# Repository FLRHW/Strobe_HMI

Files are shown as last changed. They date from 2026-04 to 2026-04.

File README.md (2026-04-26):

<h1 align="center">HMI board</h1>

<p align="center" width="100%">
  <a href="https://github.com/FLRHW/Strobe_HMI/actions/workflows/ci.yaml">
    
  </a>
</p>

<p align="center" width="100%">
    
</p>

***

<p align="center">
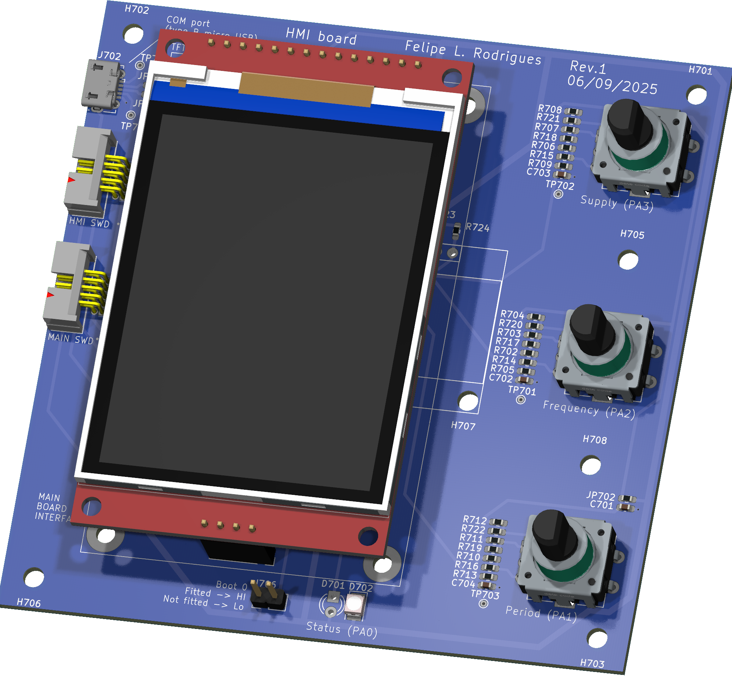
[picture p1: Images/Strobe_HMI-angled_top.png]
3D Top Angled
  
&nbsp; &nbsp; &nbsp; &nbsp;
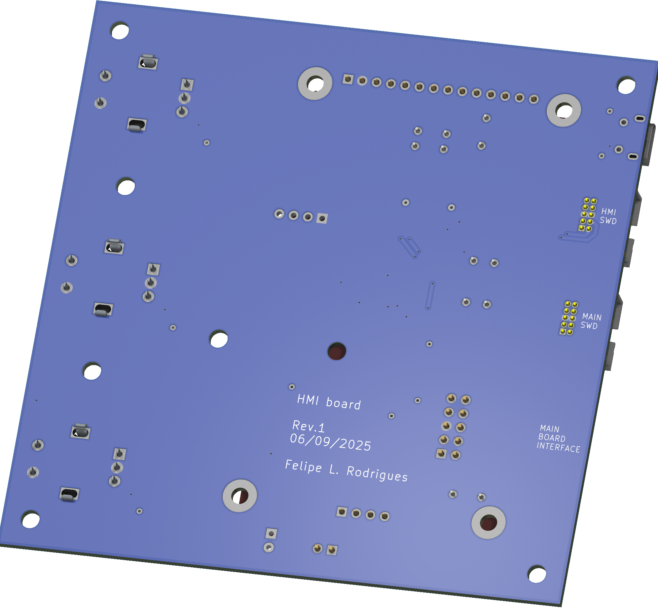
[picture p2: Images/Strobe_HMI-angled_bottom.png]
3D Bottom Angled
  
</p>

***

# **1 kV strobe - Intro**
Since my tenage years I spend a great chunk of my spare time on hobby electronics. Back then, much of that time was to build FM transmitters, audio amplifiers and strobe lights. I was always pushing my builds as much as I could, (i.e., extracting pressurised smoke from capacitors!) as an attempt to make the flashes ever brighter. It was somewhat challenging given the limited experience and resources I had at the time, but a lot of fun nonetheless.
Life went on, priorities changed and for a long time I did not "play" with strobe lights... until recently, after I bumped into an ebay page of a large XOP-15 bulb and, well, nostalgy happened.

While defining the project scope, I had to decide if I'd use the good old Xenon bulb or move to LEDs, as these have greatly evolved and are ubiquitous nowadays, making their way to commercial strobes (https://www.martin.com/en/products/atomic-3000-led). I have decided to stick to vintage tech, as in my mind this would perhaps bring more interesting power electronics challenges, since the bulb requires a somewhat high bus voltage and can draw very high peak currents when ionised.

So that's what this repo contains: a Xenon-based strobe light, aiming to drive a XOP-15 bulb with up to 1 kV, while controlling the duration and frequency of pulses.

## Project overview
This repository contains KiCad v9 design files for the HMI board of a Xenon-based strobe light system.
The system is divided into three separate boards:
- HMI - so the user can set desired operating conditions (bus voltage, pulse width and pulse frequency)
- Main board - drives the Xenon bulb, generating the trigger pulse and actively interrupting the discharge according to the required pulse width
- Power supply - to produce an adjustable DC supply. To realise that I intend to eventually design an AC-mains powered converter, including a PFC circuit. As an interim solution, off-the-shelf boost converter modules are used: two such modules are connected in series, each providing up to 450 V output while supplied by 12 V batteries.

Working prototypes exist for both the HMI and main board. This repository covers only the HMI board. The main board is available on its own repo:
https://github.com/FLRHW/Strobe_main

The source code is kept on a separate repo:
https://github.com/FLRHW/Strobe_HMI_source

As a side project, the boost modules have been reverse engineered with the aim to modify them from non-isolated to isolated. This work is covered under the following repos:
- https://github.com/FLRHW/StepUp_module_12to450V
- https://github.com/FLRHW/Isolated_12to450V.

## Design targets
DC bus voltage: 400 V to 1000 V  
Flash rate: 0.1 Hz to 100 Hz  
Pulse duration: 20 μs to 10 ms  

Please note that extremes are not simultaneously achievable. This design relies on storing energy on a capacitor bank to then discharge it into the bulb, hence some time must be reserved for storing that energy. The pulse duration is currently limited in SW to 50 % of the period as a safeguard, but for practical use it must be a much lower percentage.

Also, the output capacitors currently in use are not large enough to reach 10 ms pulse duration - at least not at high output voltages as the bulb current seems to increase non linearly with the bus voltage.

## Intended use
This repository is intended for:
* Educational use and study of the circuit;
* Integration into hobby or research projects.

## License
The design files and documentation in this repository are released under the CERN Open Hardware Licence v2 – Permissive (CERN‑OHL‑P‑2.0). SPDX identifier: CERN-OHL-P-2.0 See the LICENSE file for the full legal text and conditions.
In short and non‑legal terms, you are free to use, modify, manufacture, and distribute hardware based on these files, provided you respect attribution requirements and the terms in the license.

## Trademarks and third‑party rights
All product names, logos, and brands eventually mentioned are the property of their respective owners and are not included or licensed here.
Any reference to third‑party marks is purely descriptive and does not imply endorsement or affiliation.

## Safety and disclaimer
* The author takes no responsibility for any injury, death or damage arising from the use, direct or indirect, of the design or otherwise any information from this repository
* You shall not build this or any prototype based on this design unless you are absolutely sure of your abilities dealing with this type of circuit
* High voltage can cause injury, death, or damage to equipment. Ensure appropriate protections and testing procedures are followed
* The design is provided as is, with no warranty of any kind
* Users are responsible for checking any patent, copyright, or regulatory constraints that may apply to their own use

***

## DIRECTORY STRUCTURE
    │
    ├─ Computations       # Misc calculations
    ├─ HTML               # HTML files for generated webpage
    ├─ Images             # Pictures and renders
    │
    ├─ kibot_resources    # External resources for KiBot
    │  ├─ colors          # Color theme for KiCad
    │  ├─ fonts           # Fonts used in the project
    │  ├─ scripts         # External scripts used with KiBot
    │  └─ templates       # Templates for KiBot generated reports
    │
    ├─ kibot_yaml         # KiBot YAML config files
    ├─ KiRI               # KiRI (PCB diff viewer) files
    │
    ├─ lib                # KiCad footprint and symbol libraries
    │  ├─ 3d_models       # Component 3D models
    │  ├─ lib_fp          # Footprint libraries
    │  └─ lib_sym         # Symbol libraries
    │
    ├─ Logos              # Logos
    │
    ├─ Manufacturing      # Assembly and fabrication documents
    │  ├─ Assembly        # Assembly documents (BoM, pos, notes)
    │  │
    │  └─ Fabrication     # Fabrication documents (ZIP, notes)
    │     ├─ Drill Tables # CSV drill tables
    │     └─ Gerbers      # Gerbers
    │
    ├─ Report             # Reports for ERC/DRC
    ├─ Schematic          # PDF of schematic
    ├─ Templates          # Title block templates
    ├─ Testing
    │  └─ Testpoints      # Testpoints tables      
    │
    └─ Variants           # Outputs for assembly variants

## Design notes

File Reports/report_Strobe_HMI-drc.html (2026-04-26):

Logo

(https://github.com/INTI-CMNB/KiBot/) | DRC report for Strobe_HMI
| PCB: Strobe_HMI Revision: 1.0.1 Date: 2026-04-26T08:03:34+0000 KiCad Version: 9.0.7 | Errors: 0 Warnings: 4 Total: 4

Violations

Type | Description | Details
silk_over_copper | Silkscreen clipped by solder mask | @(191.527 mm, 80.502 mm): Circle of JP703 on F.Silkscreen
silk_over_copper | Silkscreen clipped by solder mask | @(199.655 mm, 80.502 mm): Circle of JP703 on F.Silkscreen
silk_over_copper | Silkscreen clipped by solder mask | @(204.9425 mm, 110.6995 mm): Segment of OLED701 on F.Silkscreen
silk_over_copper | Silkscreen clipped by solder mask | @(205.0425 mm, 105.6995 mm): Segment of OLED701 on F.Silkscreen

Generated by KiBot (https://github.com/INTI-CMNB/KiBot/) v1.8.6

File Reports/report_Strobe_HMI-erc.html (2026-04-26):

Logo

(https://github.com/INTI-CMNB/KiBot/) | ERC report for Strobe_HMI
| Schematic: Strobe_HMI Revision: 1.0.1 Date: 2026-04-26T08:03:33+0000 KiCad Version: 9.0.7 | Errors: 0 Warnings: 81 Total: 81

Sheet / (Strobe_HMI.kicad_sch)

Type | Description | Details
lib_symbol_issues | The current configuration does not include the symbol library 'personal' | @(0.2921 mm, 0.2667 mm): Symbol P1 [Cosmetic_PWR]
lib_symbol_issues | The current configuration does not include the symbol library 'personal' | @(0.2032 mm, 0.381 mm): Symbol P8 [Cosmetic_IN]
lib_symbol_issues | The current configuration does not include the symbol library 'personal' | @(0.2794 mm, 0.4572 mm): Symbol P5 [Cosmetic_IN]
lib_symbol_issues | The current configuration does not include the symbol library 'personal' | @(0.2794 mm, 0.4826 mm): Symbol P4 [Cosmetic_OUT]
lib_symbol_issues | The current configuration does not include the symbol library 'personal' | @(0.5842 mm, 0.381 mm): Symbol P7 [Cosmetic_IN]
lib_symbol_issues | The current configuration does not include the symbol library 'personal' | @(0.5842 mm, 0.4064 mm): Symbol P6 [Cosmetic_IO]
lib_symbol_issues | The current configuration does not include the symbol library 'personal' | @(0.635 mm, 0.4064 mm): Symbol P3 [Cosmetic_PWR_SRC]
footprint_link_issues | The current configuration does not include the footprint library 'Personal'. | @(0.2794 mm, 0.8255 mm): Symbol J702 [USB_B_Micro]
lib_symbol_issues | The current configuration does not include the symbol library 'personal' | @(0.8509 mm, 0.2413 mm): Symbol P730 [Cosmetic_PWR]
lib_symbol_issues | The current configuration does not include the symbol library 'personal' | @(0.635 mm, 0.8255 mm): Symbol P732 [Cosmetic_IO]
lib_symbol_issues | The current configuration does not include the symbol library 'personal' | @(0.635 mm, 0.8509 mm): Symbol P736 [Cosmetic_IO]
lib_symbol_issues | The current configuration does not include the symbol library 'personal' | @(0.1778 mm, 1.1938 mm): Symbol P791 [Cosmetic_PWR]
footprint_link_issues | The current configuration does not include the footprint library 'Personal'. | @(1.1938 mm, 0.254 mm): Symbol JP703 [Jumper_2_Bridged]
lib_symbol_issues | The current configuration does not include the symbol library 'personal' | @(0.1905 mm, 1.2573 mm): Symbol P799 [Cosmetic_IN]
lib_symbol_issues | The current configuration does not include the symbol library 'personal' | @(1.1938 mm, 0.4572 mm): Symbol P739 [Cosmetic_PWR]
footprint_link_issues | The current configuration does not include the footprint library 'Personal'. | @(0.3556 mm, 1.2319 mm): Symbol J707 [Conn_02x05_Odd_Even]
lib_symbol_issues | The current configuration does not include the symbol library 'personal' | @(0.1905 mm, 1.2827 mm): Symbol P802 [Cosmetic_OUT]
lib_symbol_issues | The current configuration does not include the symbol library 'personal' | @(0.5588 mm, 1.1938 mm): Symbol P792 [Cosmetic_PWR]
lib_symbol_issues | The current configuration does not include the symbol library 'personal' | @(1.2192 mm, 0.508 mm): Symbol P744 [Cosmetic_IN]
lib_symbol_issues | The current configuration does not include the symbol library 'personal' | @(1.1938 mm, 0.635 mm): Symbol P751 [Cosmetic_OUT]
lib_symbol_issues | The current configuration does not include the symbol library 'personal' | @(1.1938 mm, 0.6604 mm): Symbol P754 [Cosmetic_OUT]
lib_symbol_issues | The current configuration does not include the symbol library 'personal' | @(0.5461 mm, 1.2573 mm): Symbol P800 [Cosmetic_IO]
lib_symbol_issues | The current configuration does not include the symbol library 'personal' | @(1.1938 mm, 0.6858 mm): Symbol P757 [Cosmetic_IN]
lib_symbol_issues | The current configuration does not include the symbol library 'personal' | @(0.5461 mm, 1.2827 mm): Symbol P803 [Cosmetic_OUT]
lib_symbol_issues | The current configuration does not include the symbol library 'personal' | @(1.1938 mm, 0.7366 mm): Symbol P763 [Cosmetic_OUT]
lib_symbol_issues | The current configuration does not include the symbol library 'personal' | @(1.1938 mm, 0.762 mm): Symbol P766 [Cosmetic_IN]
lib_symbol_issues | The current configuration does not include the symbol library 'personal' | @(1.1938 mm, 0.7874 mm): Symbol P769 [Cosmetic_IN]
lib_symbol_issues | The current configuration does not include the symbol library 'personal' | @(0.8128 mm, 1.1938 mm): Symbol P749 [Cosmetic_PWR]
lib_symbol_issues | The current configuration does not include the symbol library 'personal' | @(0.1778 mm, 1.4732 mm): Symbol P793 [Cosmetic_PWR]
footprint_link_issues | The current configuration does not include the footprint library 'Personal'. | @(0.3556 mm, 1.5113 mm): Symbol J708 [Conn_02x05_Odd_Even]
lib_symbol_issues | The current configuration does not include the symbol library 'personal' | @(0.6731 mm, 1.4097 mm): Symbol P773 [Cosmetic_IN]
lib_symbol_issues | The current configuration does not include the symbol library 'personal' | @(0.1905 mm, 1.5621 mm): Symbol P804 [Cosmetic_OUT]
lib_symbol_issues | The current configuration does not include the symbol library 'personal' | @(0.5588 mm, 1.4732 mm): Symbol P794 [Cosmetic_PWR]
lib_symbol_issues | The current configuration does not include the symbol library 'personal' | @(0.5461 mm, 1.5367 mm): Symbol P801 [Cosmetic_IO]
lib_symbol_issues | The current configuration does not include the symbol library 'personal' | @(0.5461 mm, 1.5621 mm): Symbol P805 [Cosmetic_OUT]
lib_symbol_issues | The current configuration does not include the symbol library 'personal' | @(1.778 mm, 0.508 mm): Symbol P745 [Cosmetic_OUT]
footprint_link_issues | The current configuration does not include the footprint library 'Personal'. | @(1.1684 mm, 1.4351 mm): Symbol SW701 [RotaryEncoder_Switch]
lib_symbol_issues | The current configuration does not include the symbol library 'personal' | @(1.778 mm, 0.5334 mm): Symbol P746 [Cosmetic_IN]
lib_symbol_issues | The current configuration does not include the symbol library 'personal' | @(1.778 mm, 0.5588 mm): Symbol P747 [Cosmetic_IN]
lib_symbol_issues | The current configuration does not include the symbol library 'personal' | @(1.778 mm, 0.5842 mm): Symbol P748 [Cosmetic_IN]
lib_symbol_issues | The current configuration does not include the symbol library 'personal' | @(1.778 mm, 0.6096 mm): Symbol P750 [Cosmetic_OUT]
lib_symbol_issues | The current configuration does not include the symbol library 'personal' | @(1.778 mm, 0.635 mm): Symbol P752 [Cosmetic_OUT]
lib_symbol_issues | The current configuration does not include the symbol library 'personal' | @(1.778 mm, 0.6604 mm): Symbol P755 [Cosmetic_IN]
lib_symbol_issues | The current configuration does not include the symbol library 'personal' | @(1.8796 mm, 0.2921 mm): Symbol P733 [Cosmetic_PWR]
lib_symbol_issues | The current configuration does not include the symbol library 'personal' | @(1.778 mm, 0.6858 mm): Symbol P758 [Cosmetic_OUT]
lib_symbol_issues | The current configuration does not include the symbol library 'personal' | @(1.778 mm, 0.7112 mm): Symbol P761 [Cosmetic_IO]
lib_symbol_issues | The current configuration does not include the symbol library 'personal' | @(1.778 mm, 0.7366 mm): Symbol P764 [Cosmetic_OUT]
lib_symbol_issues | The current configuration does not include the symbol library 'personal' | @(1.778 mm, 0.762 mm): Symbol P767 [Cosmetic_OUT]
lib_symbol_issues | The current configuration does not include the symbol library 'personal' | @(1.778 mm, 0.7874 mm): Symbol P770 [Cosmetic_IO]
lib_symbol_issues | The current configuration does not include the symbol library 'personal' | @(1.778 mm, 0.8128 mm): Symbol P772 [Cosmetic_IO]
lib_symbol_issues | The current configuration does not include the symbol library 'personal' | @(1.9304 mm, 0.3302 mm): Symbol P731 [Cosmetic_IO]
lib_symbol_issues | The current configuration does not include the symbol library 'personal' | @(1.9304 mm, 0.3556 mm): Symbol P734 [Cosmetic_IN]
lib_symbol_issues | The current configuration does not include the symbol library 'personal' | @(1.778 mm, 0.8382 mm): Symbol P775 [Cosmetic_IO]
lib_symbol_issues | The current configuration does not include the symbol library 'personal' | @(1.778 mm, 0.8636 mm): Symbol P777 [Cosmetic_IN]
lib_symbol_issues | The current configuration does not include the symbol library 'personal' | @(1.778 mm, 0.889 mm): Symbol P782 [Cosmetic_IN]
lib_symbol_issues | The current configuration does not include the symbol library 'personal' | @(1.8923 mm, 0.6858 mm): Symbol P789 [Cosmetic_PWR]
lib_symbol_issues | The current configuration does not include the symbol library 'personal' | @(1.4986 mm, 1.3589 mm): Symbol P714 [Cosmetic_OUT]
lib_symbol_issues | The current configuration does not include the symbol library 'personal' | @(2.032 mm, 0.2032 mm): Symbol P728 [Cosmetic_PWR]
lib_symbol_issues | The current configuration does not include the symbol library 'personal' | @(2.1209 mm, 0.2032 mm): Symbol P729 [Cosmetic_PWR]
lib_symbol_issues | The current configuration does not include the symbol library 'personal' | @(1.9939 mm, 0.7874 mm): Symbol P790 [Cosmetic_OUT]
footprint_link_issues | The current configuration does not include the footprint library 'Personal'. | @(1.6764 mm, 1.4351 mm): Symbol SW702 [RotaryEncoder_Switch]
footprint_link_issues | The current configuration does not include the footprint library 'Personal'. | @(2.2352 mm, 0.254 mm): Symbol OLED701 [OLED_128x64_SSD1306_no_pins]
lib_symbol_issues | The current configuration does not include the symbol library 'personal' | @(2.2352 mm, 0.254 mm): Symbol OLED701 [OLED_128x64_SSD1306_no_pins]
lib_symbol_issues | The current configuration does not include the symbol library 'personal' | @(2.1082 mm, 0.8001 mm): Symbol P771 [Cosmetic_PWR]
footprint_link_issues | The current configuration does not include the footprint library 'Personal'. | @(2.2352 mm, 0.7493 mm): Symbol TFT701 [TFT_2.8_IN_320x240]
lib_symbol_issues | The current configuration does not include the symbol library 'personal' | @(2.2352 mm, 0.7493 mm): Symbol TFT701 [TFT_2.8_IN_320x240]
lib_symbol_issues | The current configuration does not include the symbol library 'personal' | @(2.0066 mm, 1.3589 mm): Symbol P715 [Cosmetic_OUT]
lib_symbol_issues | The current configuration does not include the symbol library 'personal' | @(2.413 mm, 0.6604 mm): Symbol P753 [Cosmetic_OUT]
lib_symbol_issues | The current configuration does not include the symbol library 'personal' | @(2.413 mm, 0.6858 mm): Symbol P756 [Cosmetic_OUT]
lib_symbol_issues | The current configuration does not include the symbol library 'personal' | @(2.413 mm, 0.7112 mm): Symbol P760 [Cosmetic_IN]
lib_symbol_issues | The current configuration does not include the symbol library 'personal' | @(2.413 mm, 0.7366 mm): Symbol P762 [Cosmetic_IN]
lib_symbol_issues | The current configuration does not include the symbol library 'personal' | @(2.413 mm, 0.762 mm): Symbol P765 [Cosmetic_IN]
lib_symbol_issues | The current configuration does not include the symbol library 'personal' | @(2.413 mm, 0.7874 mm): Symbol P768 [Cosmetic_OUT]
lib_symbol_issues | The current configuration does not include the symbol library 'personal' | @(2.413 mm, 0.8382 mm): Symbol P774 [Cosmetic_IN]
lib_symbol_issues | The current configuration does not include the symbol library 'personal' | @(2.413 mm, 0.8636 mm): Symbol P776 [Cosmetic_IN]
lib_symbol_issues | The current configuration does not include the symbol library 'personal' | @(2.413 mm, 0.889 mm): Symbol P781 [Cosmetic_IN]
lib_symbol_issues | The current configuration does not include the symbol library 'personal' | @(2.413 mm, 0.9144 mm): Symbol P784 [Cosmetic_IN]
lib_symbol_issues | The current configuration does not include the symbol library 'personal' | @(2.413 mm, 0.9398 mm): Symbol P786 [Cosmetic_IN]
footprint_link_issues | The current configuration does not include the footprint library 'Personal'. | @(2.1844 mm, 1.4351 mm): Symbol SW703 [RotaryEncoder_Switch]
lib_symbol_issues | The current configuration does not include the symbol library 'personal' | @(2.5146 mm, 1.3589 mm): Symbol P716 [Cosmetic_OUT]
lib_symbol_issues | The current configuration does not include the symbol library 'personal' | @(2.6797 mm, 1.1303 mm): Symbol P706 [Cosmetic_PWR]

Generated by KiBot (https://github.com/INTI-CMNB/KiBot/) v1.8.6

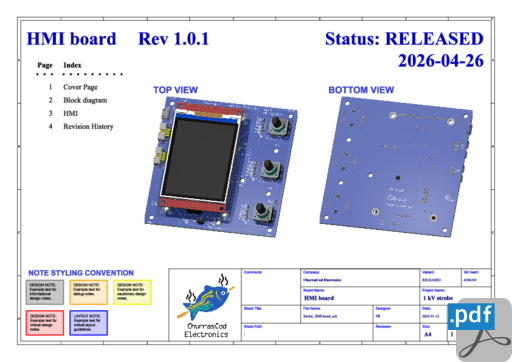
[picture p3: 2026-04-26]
HTML/images/cat_pdf_schematic_Strobe_HMI-schematic.png

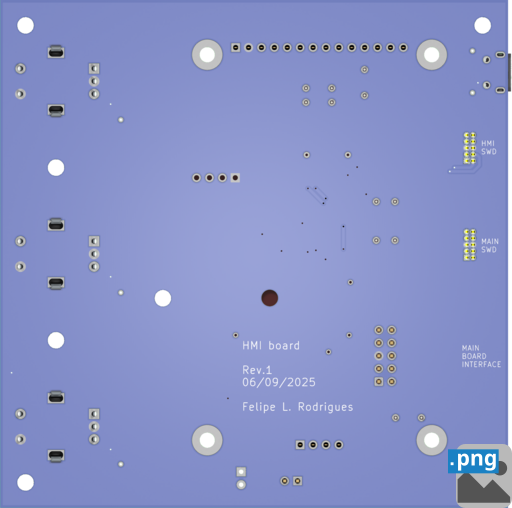
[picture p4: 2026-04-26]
HTML/images/cat_png_3d_viewer_bottom_Strobe_HMI-bottom.png

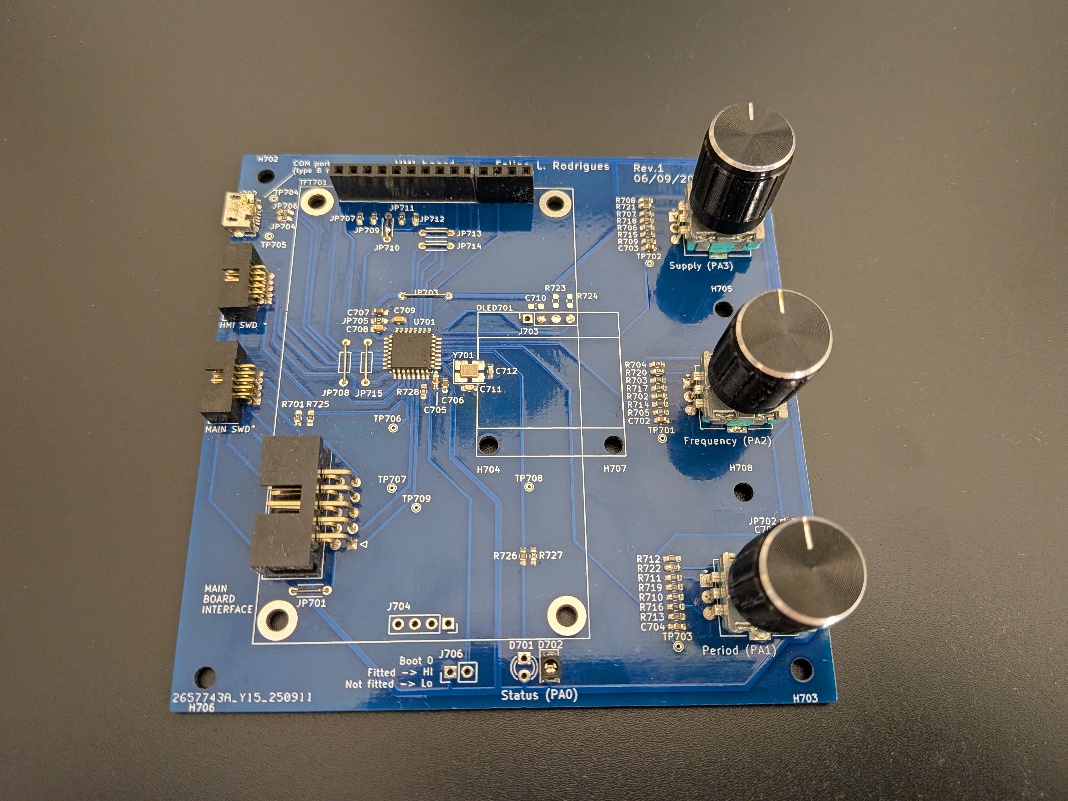
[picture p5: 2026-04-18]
Images/TOP.jpg

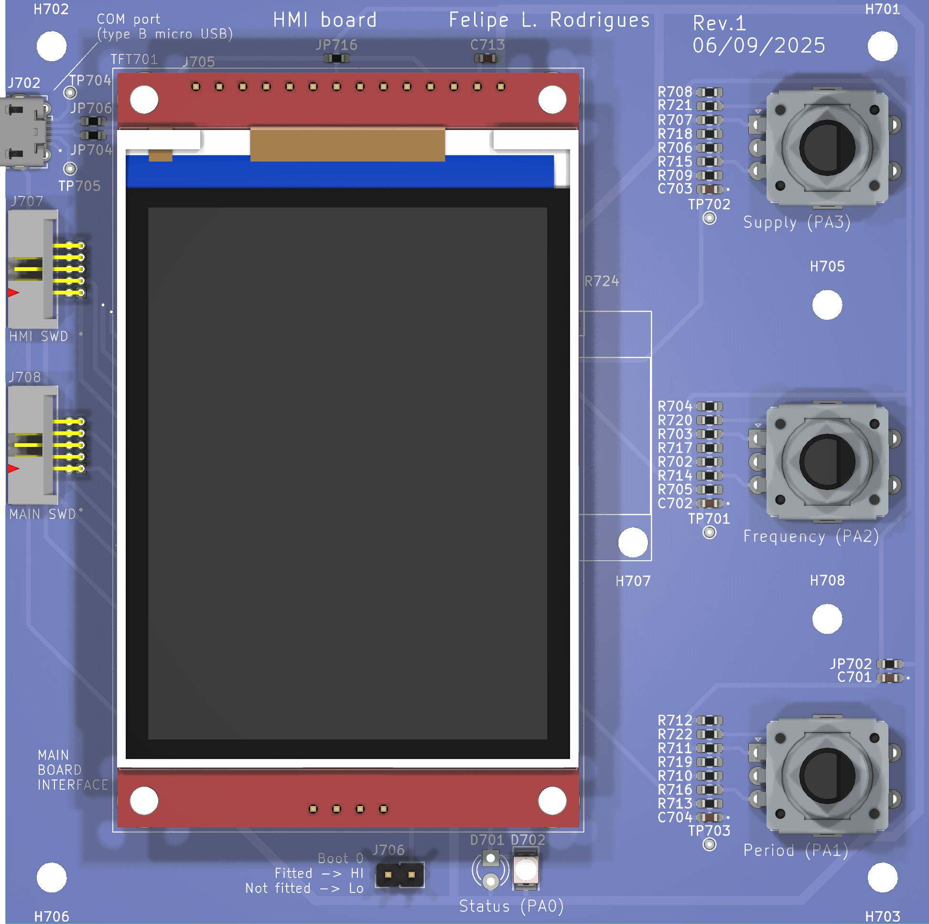
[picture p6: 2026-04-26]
Images/Strobe_HMI-top.png

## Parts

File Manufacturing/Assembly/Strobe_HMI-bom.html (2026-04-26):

 | Bill of Materials
 | Schematic: Strobe_HMI Variant: RELEASED Revision: 1.0.1 Date: 2025-01-12 KiCad Version: 9.0.7+1 | Component Groups: 23 Component Count: 74 (per PCB) Fitted Components: 70 (per PCB) Number of PCBs: 1 Total Components: 70 (for 1 PCBs)
Row | Quantity Per PCB | References | Value | Datasheet | Footprint | Description | Manufacturer | Manufacturer Part Number | Supplier Part Number
1 | 2 | C711 C712 | 22p | ~ | C_0603_1608Metric_Pad1.08x0.95mm_HandSolder | Unpolarized capacitor
2 | 8 | C701 C702 C703 C704 C705 C708 C709 C713 | 100n | ~ | C_0603_1608Metric_Pad1.08x0.95mm_HandSolder | Unpolarized capacitor
3 | 2 | C706 C707 | 1u | ~ | C_0603_1608Metric_Pad1.08x0.95mm_HandSolder | Unpolarized capacitor
4 | 1 | D702 | LED | ~ | LED_PLCC-2_3x2mm_KA | Light emitting diode | Osram | LH T6MF-GGHH-1-E3L3
5 | 7 | J701 J702 J704 J705 J706 J707 J708 | ZHOURI DC3 | ~ | IDC-Header_2x05_P2.54mm_Horizontal | Generic connector, double row, 02x05, odd/even pin numbering scheme (row 1 odd numbers, row 2 even numbers), script generated (kicad-library-utils/schlib/autogen/connector/) USB Micro Type B connector Generic connector, single row, 01x04, script generated Generic connector, single row, 01x14, script generated Generic connector, single row, 01x02, script generated
6 | 6 | JP701 JP708 JP710 JP713 JP714 JP715 | 0R | ~ | R_Axial_DIN0204_L3.6mm_D1.6mm_P5.08mm_Horizontal | Jumper | Generic | Hand cut wire
7 | 9 | JP702 JP704 JP705 JP706 JP707 JP709 JP711 JP712 JP716 | 0R | ~ | R_0603_1608Metric_Pad0.98x0.95mm_HandSolder | Jumper | Yageo | RC0603JR-130RP
8 | 1 | JP703 | 8.12 | ~ | Jumper_mm_L8.12_D1.2_H0.5 | Jumper, 2-pole, closed/bridged | Generic | Hand cut wire
9 | 10 | R702 R703 R704 R706 R707 R708 R710 R711 R712 R726 | 1k | ~ | R_0603_1608Metric_Pad0.98x0.95mm_HandSolder | Resistor
10 | 2 | R723 R724 | 4k7 | ~ | R_0603_1608Metric_Pad0.98x0.95mm_HandSolder | Resistor
11 | 4 | R701 R725 R727 R728 | 10k | ~ | R_0603_1608Metric_Pad0.98x0.95mm_HandSolder | Resistor
12 | 3 | R720 R721 R722 | 11k | ~ | R_0603_1608Metric_Pad0.98x0.95mm_HandSolder | Resistor
13 | 3 | R717 R718 R719 | 22k | ~ | R_0603_1608Metric_Pad0.98x0.95mm_HandSolder | Resistor
14 | 3 | R714 R715 R716 | 44k | ~ | R_0603_1608Metric_Pad0.98x0.95mm_HandSolder | Resistor
15 | 3 | R705 R709 R713 | 220k | ~ | R_0603_1608Metric_Pad0.98x0.95mm_HandSolder | Resistor
16 | 3 | SW701 SW702 SW703 | EncSw | ~ | RotaryEncoderSwitch_Oblong | Rotary encoder, dual channel, incremental quadrate outputs, with switch
17 | 1 | TFT701 | TFT_2.8in_320x240 |  | TFT_2.8_IN_320x240
18 | 1 | U701 | STM32G431K8Tx | https://www.st.com/resource/en/datasheet/stm32g431k8.pdf | LQFP-32_7x7mm_P0.8mm | STMicroelectronics Arm Cortex-M4 MCU, 64KB flash, 32KB RAM, 170 MHz, 1.71-3.6V, 26 GPIO, LQFP32
19 | 1 | Y701 | 20 MHz | ~ | Crystal_SMD_3225-4Pin_3.2x2.5mm_HandSoldering | Four pin crystal, GND on pins 2 and 4, small symbol
Row | Quantity Per PCB | References | Value | Datasheet | Footprint | Description | Manufacturer | Manufacturer Part Number | Supplier Part Number
1 | 1 | C710 | 100n | ~ | C_0603_1608Metric_Pad1.08x0.95mm_HandSolder | Unpolarized capacitor
2 | 1 | D701 | LED | ~ | LED_D3.0mm | Light emitting diode | Generic | Generic 3 mm LED
3 | 1 | J703 | Conn_01x04_Pin | ~ | PinSocket_1x04_P2.54mm_Vertical | Generic connector, single row, 01x04, script generated
4 | 1 | OLED701 | OLED_128x64_SSD1306 |  | OLED_SSD1306_no_pins
Color reference for columns:
KiCad Fields (default)
Generated Fields
User Fields
Empty Fields

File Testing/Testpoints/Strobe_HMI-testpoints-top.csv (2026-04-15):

Ref. | Net | X [mm] | Y [mm]
TP701 | FREQ | 86.24 | 52.38
TP702 | SUP | 86.24 | 86.42
TP703 | PER | 86.24 | 18.60
TP704 | Net-(J702-VBUS) | 17.00 | 99.98
TP705 | Net-(J702-ID) | 17.00 | 91.73
TP706 | Net-(U701-PB5) | 41.03 | 54.41
TP707 | LV_TX | 41.28 | 44.00
TP708 | ST_LED | 63.63 | 44.00
TP709 | LV_RX | 45.34 | 40.70

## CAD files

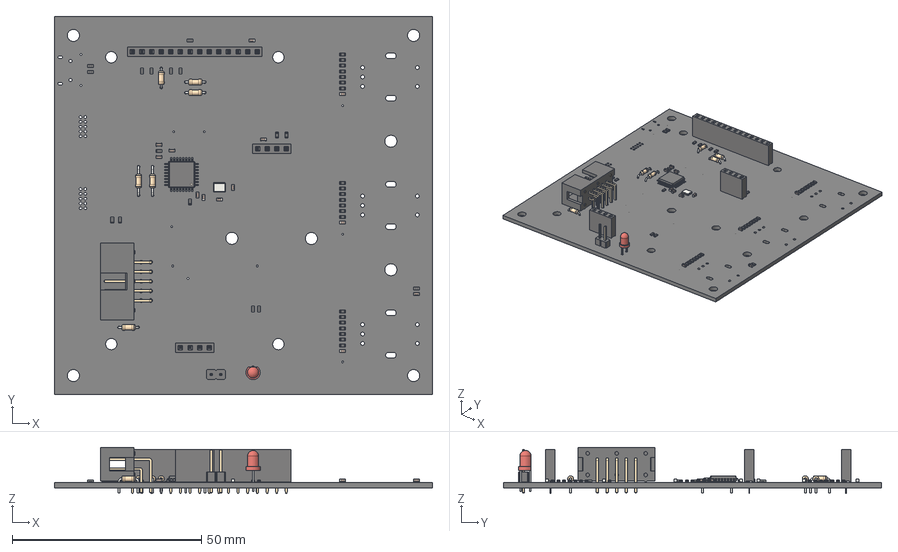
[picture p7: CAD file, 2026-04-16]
3D/Strobe_HMI.step
100.0 x 100.0 x 12.2 mm
R_0603_1608Metric x 37
LED_D3.0mm
PinSocket_1x04_P2.54mm_Vertical x 2
C_0603_1608Metric x 13
R_Axial_DIN0204_L3.6mm_D1.6mm_P5.08mm_Horizontal x 4
LQFP-32_7x7mm_P0.8mm
R_Axial_DIN0204_L3.6mm_D1.6mm_P7.62mm_Horizontal x 2
PinSocket_1x14_P2.54mm_Vertical
IDC-Header_2x05_P2.54mm_Horizontal
PinHeader_1x02_P2.54mm_Vertical
Crystal_SMD_3225-4Pin_3.2x2.5mm
kibot_q85xlfh0_PCB

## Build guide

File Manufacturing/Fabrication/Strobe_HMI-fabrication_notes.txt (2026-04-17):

FABRICATION NOTES (UNLESS OTHERWISE SPECIFIED)

1)	FABRICATE PER IPC-6012A CLASS 2.

2)	OUTLINE DEFINED IN SEPARATE GERBER FILE WITH
	"Edge_Cuts.GBR" SUFFIX.

	DIMENSIONS OF CIRCUMSIZED RECTANGLE SHOWN ON THIS
	DRAWING ARE FOR REFERENCE ONLY.

3)	SEE SEPARATE DRILL FILES WITH ".DRL" SUFFIX 
	FOR HOLE LOCATIONS.

	SELECTED HOLE LOCATIONS SHOWN ON THIS DRAWING 
	ARE FOR REFERENCE ONLY.

4)	SURFACE FINISH: HAL LEAD-FREE

5)	SOLDERMASK ON BOTH SIDES OF THE BOARD SHALL 
	BE LPI, COLOR BLUE.

6)	SILK SCREEN LEGEND TO BE APPLIED PER LAYER 
	STACKUP USING WHITE NON-CONDUCTIVE EPOXY INK.

7)	ALL VIAS ARE TENTED ON BOTH SIDES UNLESS 
	SOLDERMASK OPENED IN GERBER.

8)	VENDOR SHOULD FOLLOW ROHS COMPLIANT PROCESS 
	AND Pb FREE FOR MANUFACTURING

9)	PCB MATERIAL REQUIREMENTS:

	A.	FLAMMABILITY RATING MUST MEET OR EXCEED 
		UL94V-0 REQUIREMENTS.
	B.	Tg 170 C OR EQUIVALENT.
	C.	EQUIVALENT MATERIAL SHALL BE RoHS COMPLIANT, 
		HALOGEN FREE AND APPROVED BY CHURRASCOD ELECTRONICS.

10)	DESIGN GEOMETRY MINIMUM FEATURE SIZES:

	BOARD SIZE				100.000 × 100.000 mm
	BOARD THICKNESS		1.660 mm
	TRACE WIDTH			0.300 mm
	TRACE TO TRACE		0.180 mm
	MIN. HOLE (PTH)			0.300 mm
	MIN. HOLE (NPTH)		3.000 mm
	ANNULAR RING			0.100 mm
	COPPER TO HOLE		0.250 mm
	COPPER TO EDGE		0.500 mm
	HOLE TO HOLE			0.250 mm

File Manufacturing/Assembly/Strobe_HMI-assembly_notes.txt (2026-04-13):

ASSEMBLY NOTES (UNLESS OTHERWISE SPECIFIED)

1)	DO NOT POPULATE PARTS MARKED WITH A RED CROSS.

2)	IF CONFLICTING INFORMATION IS FOUND BETWEEN THE ASSEMBLY
	FILE AND BOM, BOM SHOULD BE USED AS THE MAIN SOURCE.

3)	DOT IDENTIFIES PIN #1 LOCATION AND DEVICE ORIENTATION
	WHEN VIEWED FROM THE TOP.

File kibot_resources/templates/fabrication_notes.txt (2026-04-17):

FABRICATION NOTES (UNLESS OTHERWISE SPECIFIED)

1)	FABRICATE PER IPC-6012A CLASS 2.

2)	OUTLINE DEFINED IN SEPARATE GERBER FILE WITH
	"Edge_Cuts.GBR" SUFFIX.

	DIMENSIONS OF CIRCUMSIZED RECTANGLE SHOWN ON THIS
	DRAWING ARE FOR REFERENCE ONLY.

3)	SEE SEPARATE DRILL FILES WITH ".DRL" SUFFIX 
	FOR HOLE LOCATIONS.

	SELECTED HOLE LOCATIONS SHOWN ON THIS DRAWING 
	ARE FOR REFERENCE ONLY.

4)	SURFACE FINISH: ${pcb_finish_cap}

5)	SOLDERMASK ON BOTH SIDES OF THE BOARD SHALL 
	BE LPI, COLOR ${solder_mask_color_text_cap}.

6)	SILK SCREEN LEGEND TO BE APPLIED PER LAYER 
	STACKUP USING ${silk_screen_color_text_cap} NON-CONDUCTIVE EPOXY INK.

7)	ALL VIAS ARE TENTED ON BOTH SIDES UNLESS 
	SOLDERMASK OPENED IN GERBER.

8)	VENDOR SHOULD FOLLOW ROHS COMPLIANT PROCESS 
	AND Pb FREE FOR MANUFACTURING

9)	PCB MATERIAL REQUIREMENTS:

	A.	FLAMMABILITY RATING MUST MEET OR EXCEED 
		UL94V-0 REQUIREMENTS.
	B.	Tg 170 C OR EQUIVALENT.
	C.	EQUIVALENT MATERIAL SHALL BE RoHS COMPLIANT, 
		HALOGEN FREE AND APPROVED BY ${COMPANY_cap}.

10)	DESIGN GEOMETRY MINIMUM FEATURE SIZES:

	BOARD SIZE				${bb_w_mm} × ${bb_h_mm} mm
	BOARD THICKNESS		${thickness_mm} mm
	TRACE WIDTH			${track_mm} mm
	TRACE TO TRACE		${clearance_mm} mm
	MIN. HOLE (PTH)			${drill_pth_real_mm} mm
	MIN. HOLE (NPTH)		${drill_npth_real_mm} mm
	ANNULAR RING			${oar_mm} mm
	COPPER TO HOLE		${c2h_mm} mm
	COPPER TO EDGE		${c2e_mm} mm
	HOLE TO HOLE			${h2h_mm} mm
#?stackup and impedance_controlled

#?stackup and impedance_controlled
11)	REFER TO IMPEDANCE TABLE FOR IMPEDANCE CONTROL REQUIREMENTS.
#?stackup and impedance_controlled

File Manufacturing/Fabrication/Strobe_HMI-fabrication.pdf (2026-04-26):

# Top Fabrication (Scale 1:1) HMI board Fabrication Document

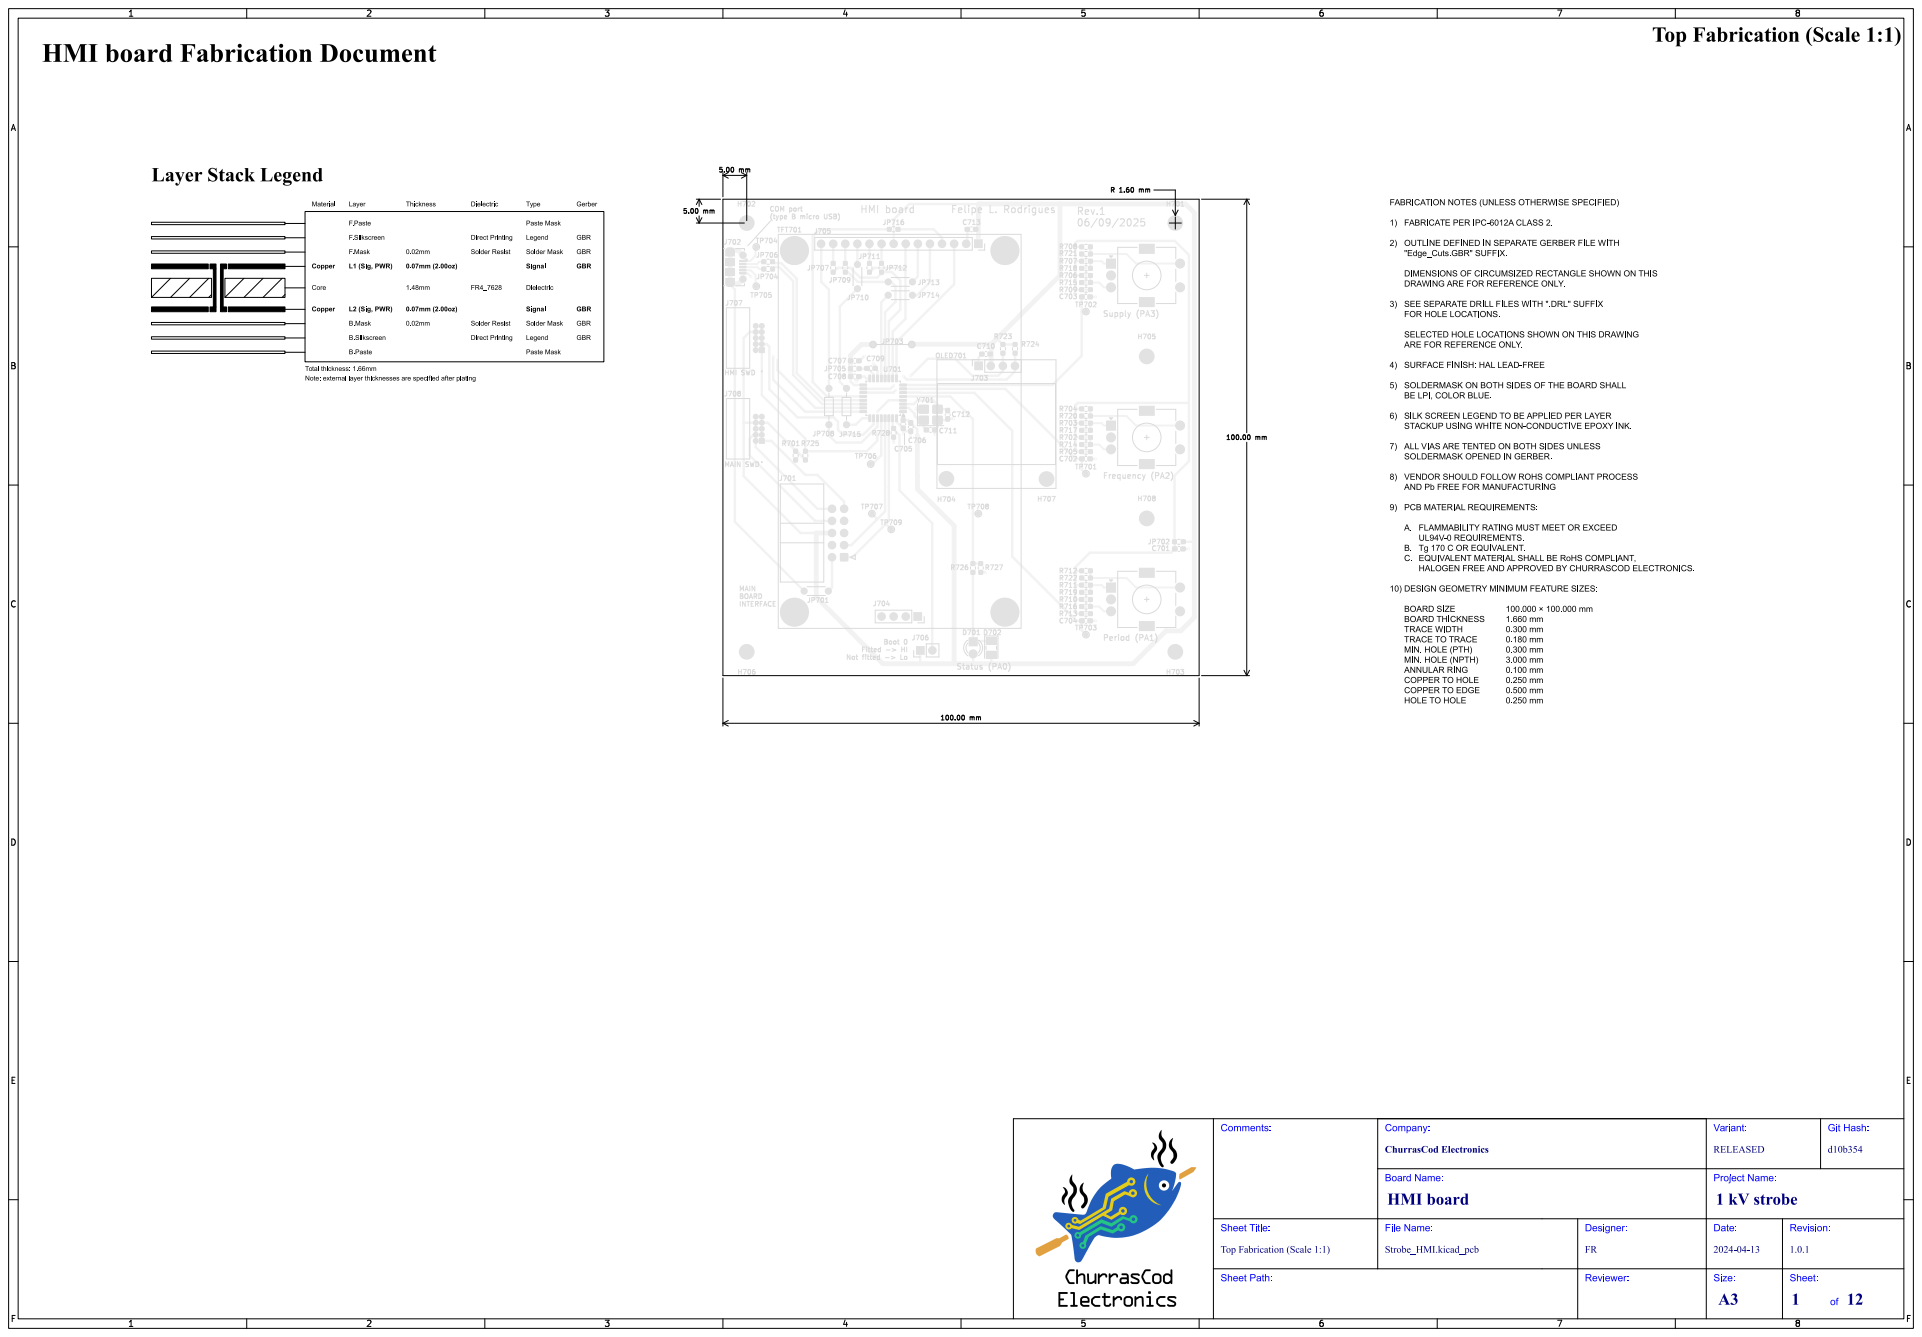
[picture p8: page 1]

# Bottom Fabrication (Scale 1:1) HMI board Fabrication Document

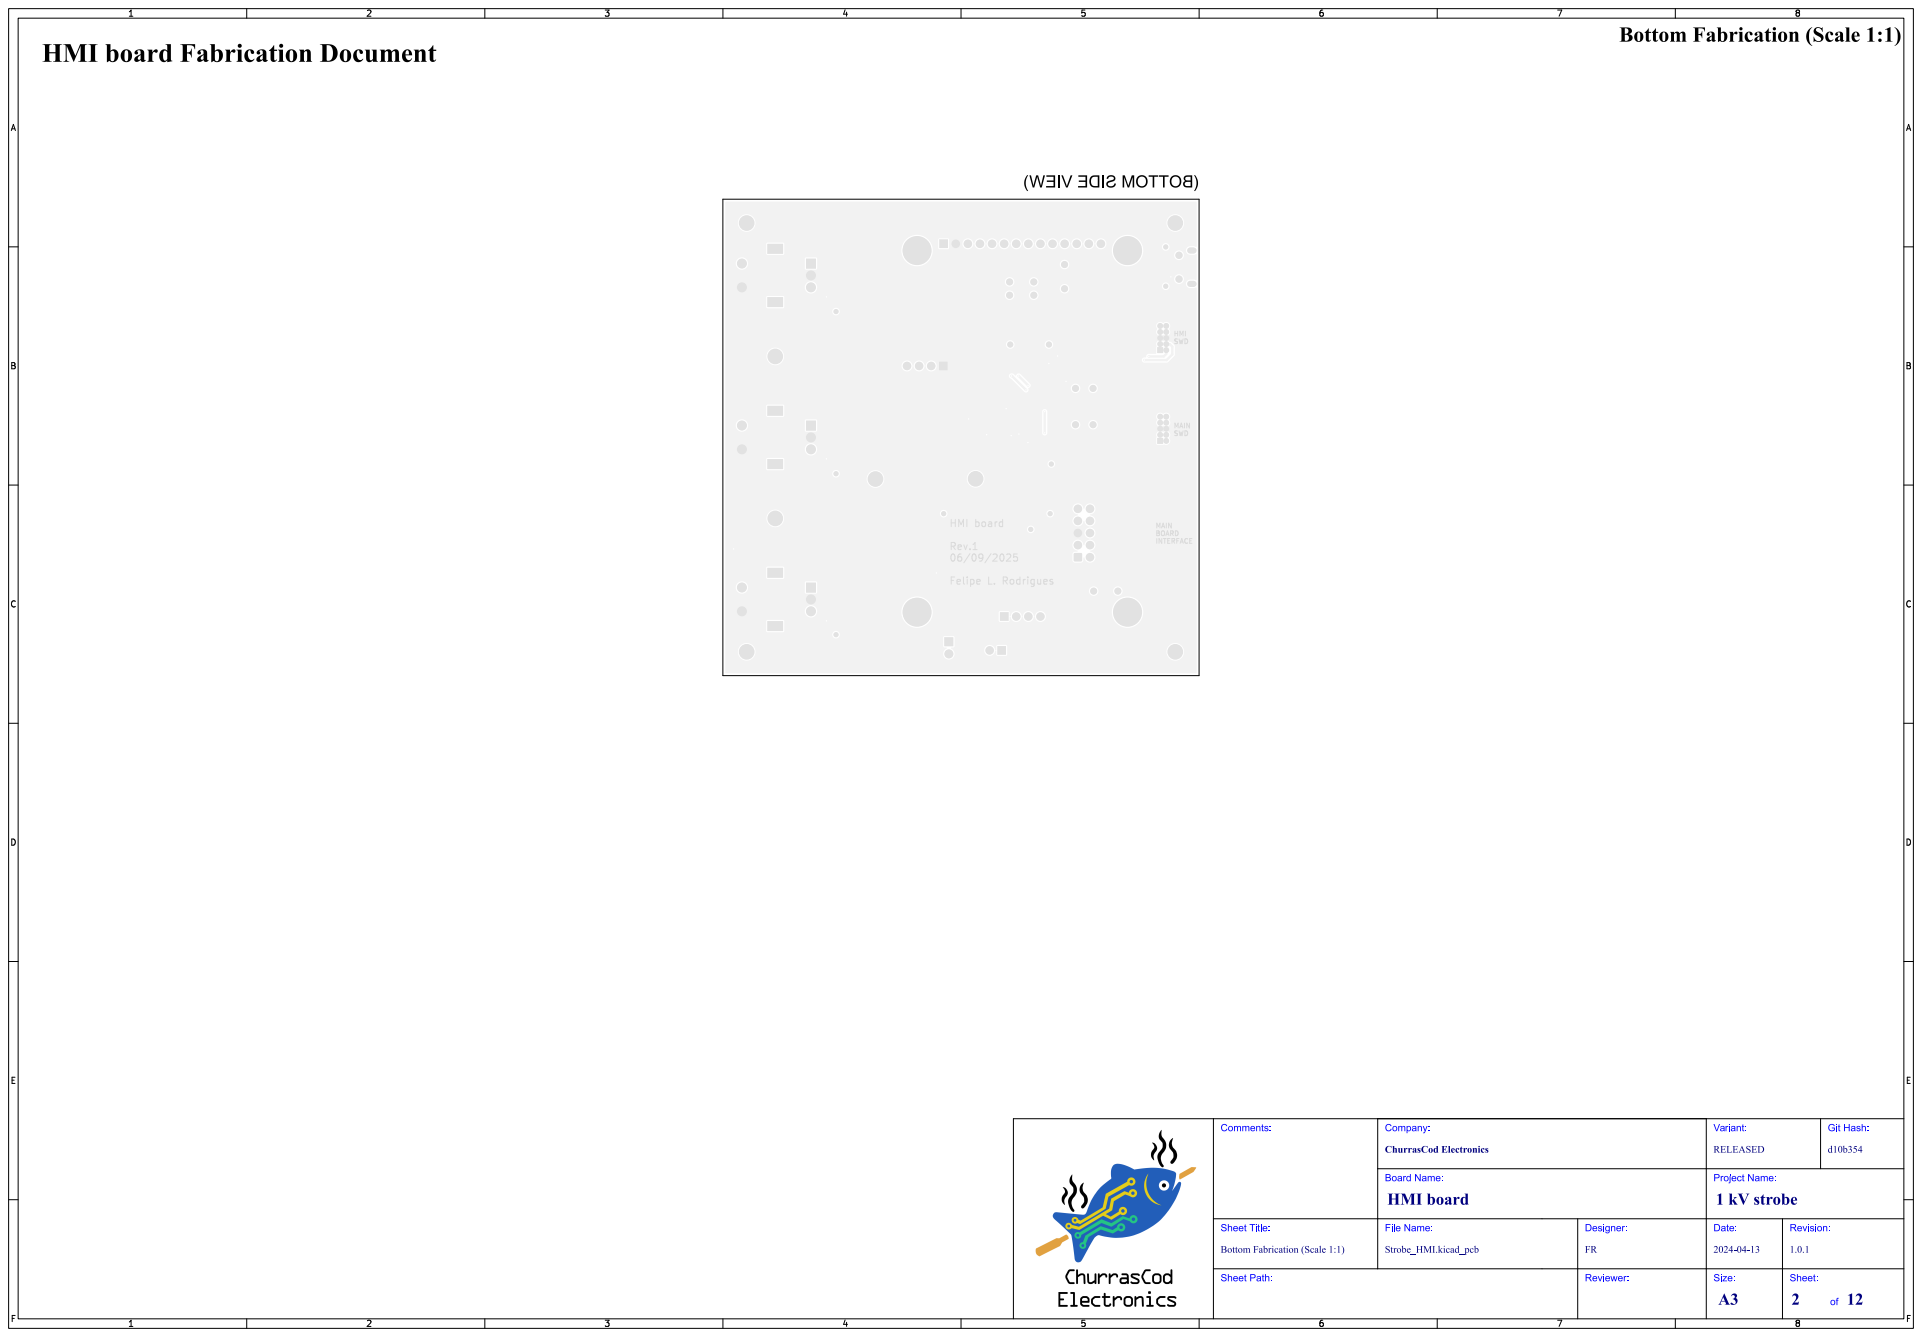
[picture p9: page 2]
Git; Hash:; Comments:; Sheet Title:; File Name:; HMI board; 1 kV strobe; ChurrasCod Electronics; Company:; RELEASED; Variant:; Board Name:; Strobe_HMI.kicad_pcb; Designer:; Project Name:; Date:; Revision:; Felipe; Rodrigues; Rev.1; HMI; board; INTERFACE; BOARD; MAIN; SWD

Bottom Fabrication (Scale 1:1)

# Drill Drawing L1 - L2 (Scale 1:1) HMI board Fabrication Document

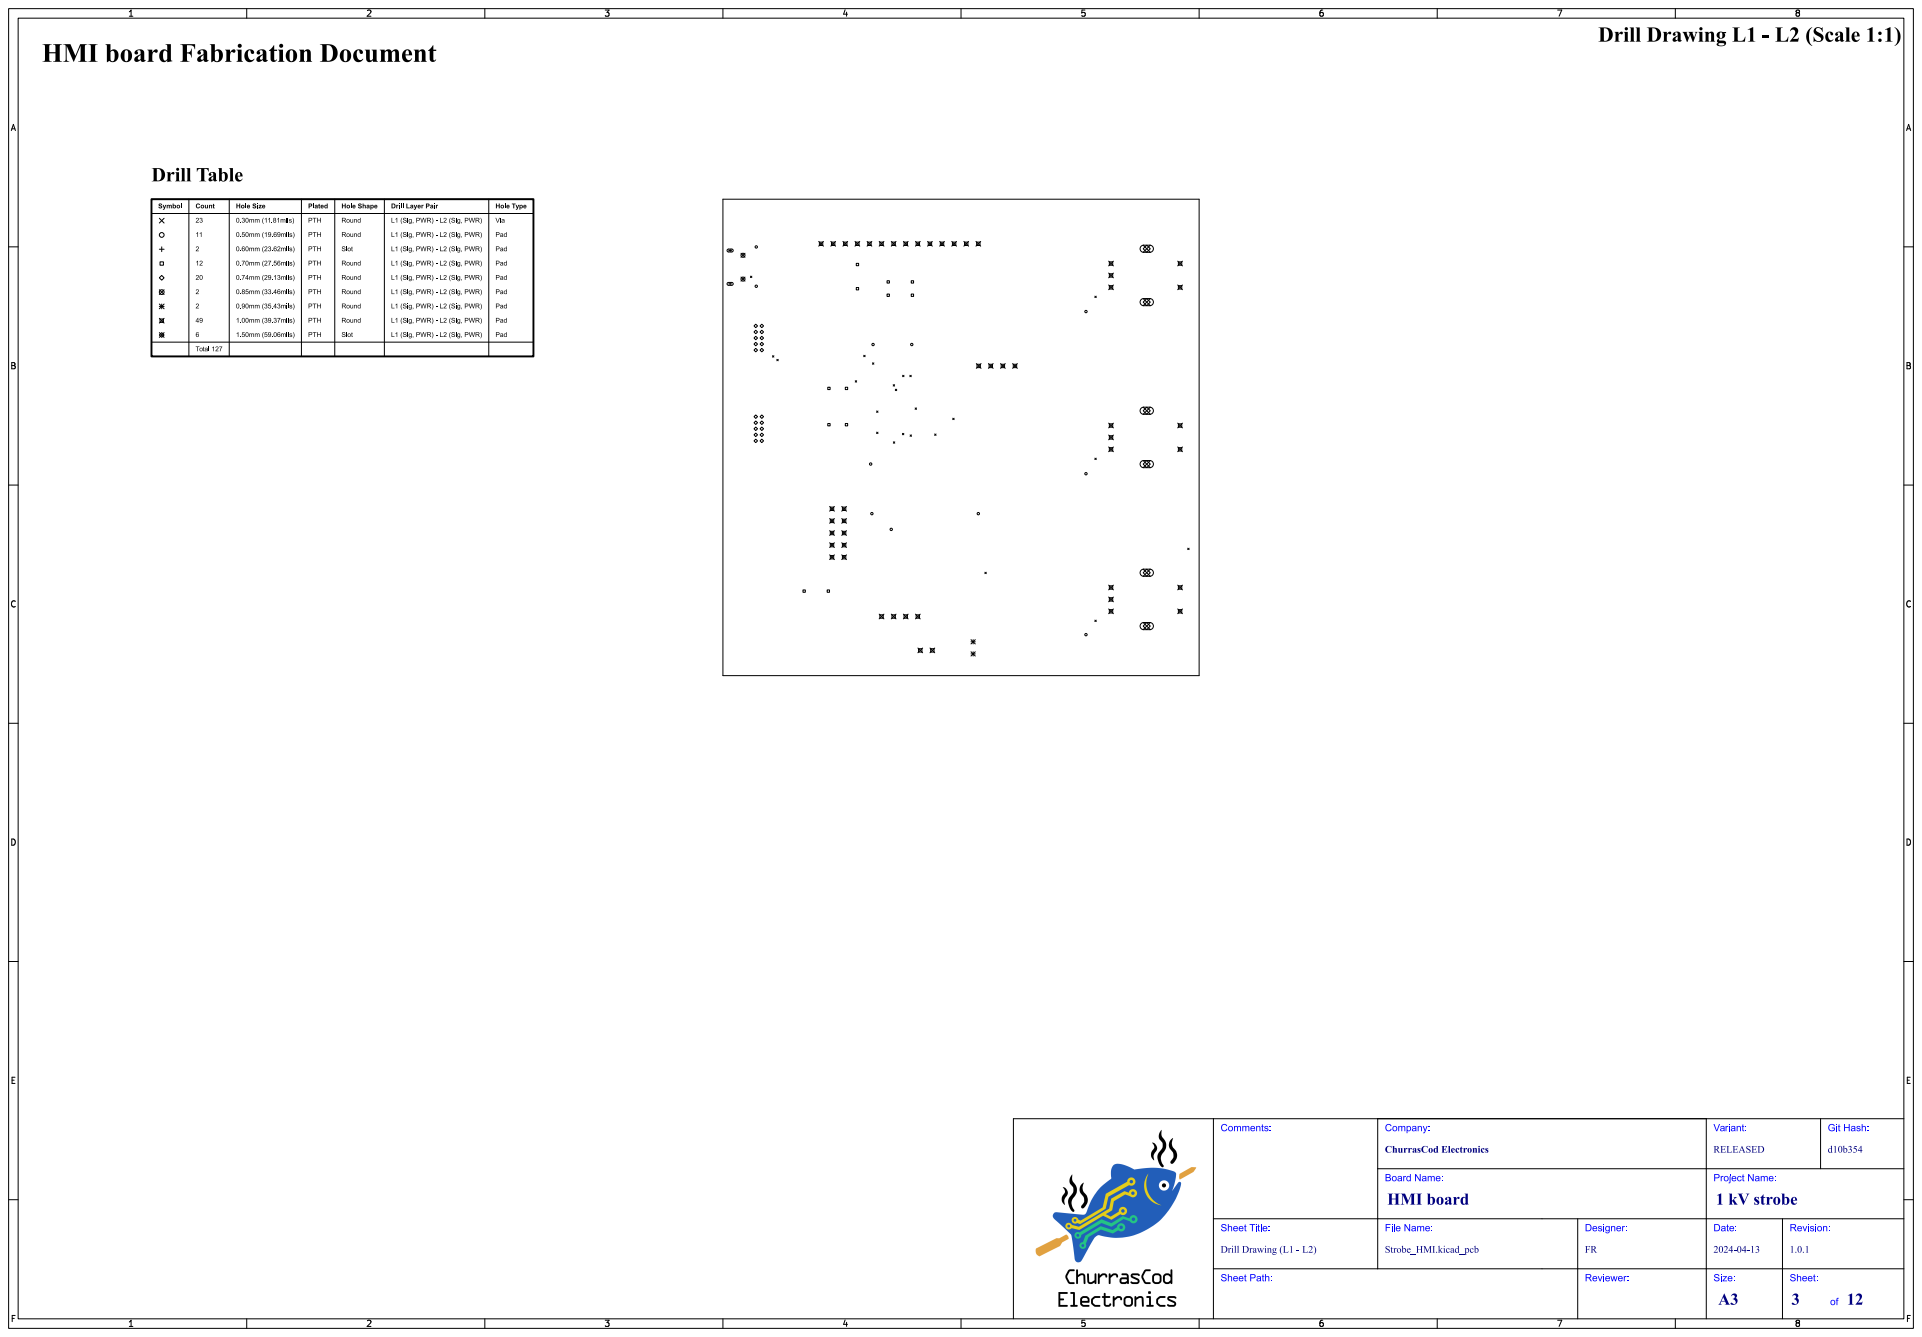
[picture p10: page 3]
Git; Hash:; Comments:; Drill Drawing (L1 - L2); Sheet Title:; File Name:; HMI board; 1 kV strobe; ChurrasCod Electronics; Company:; RELEASED; Variant:; Board Name:; Strobe_HMI.kicad_pcb; Designer:; Project Name:; Date:; Revision:

# Drill Drawing L1 - L2 (Scale 1:1) HMI board Fabrication Document

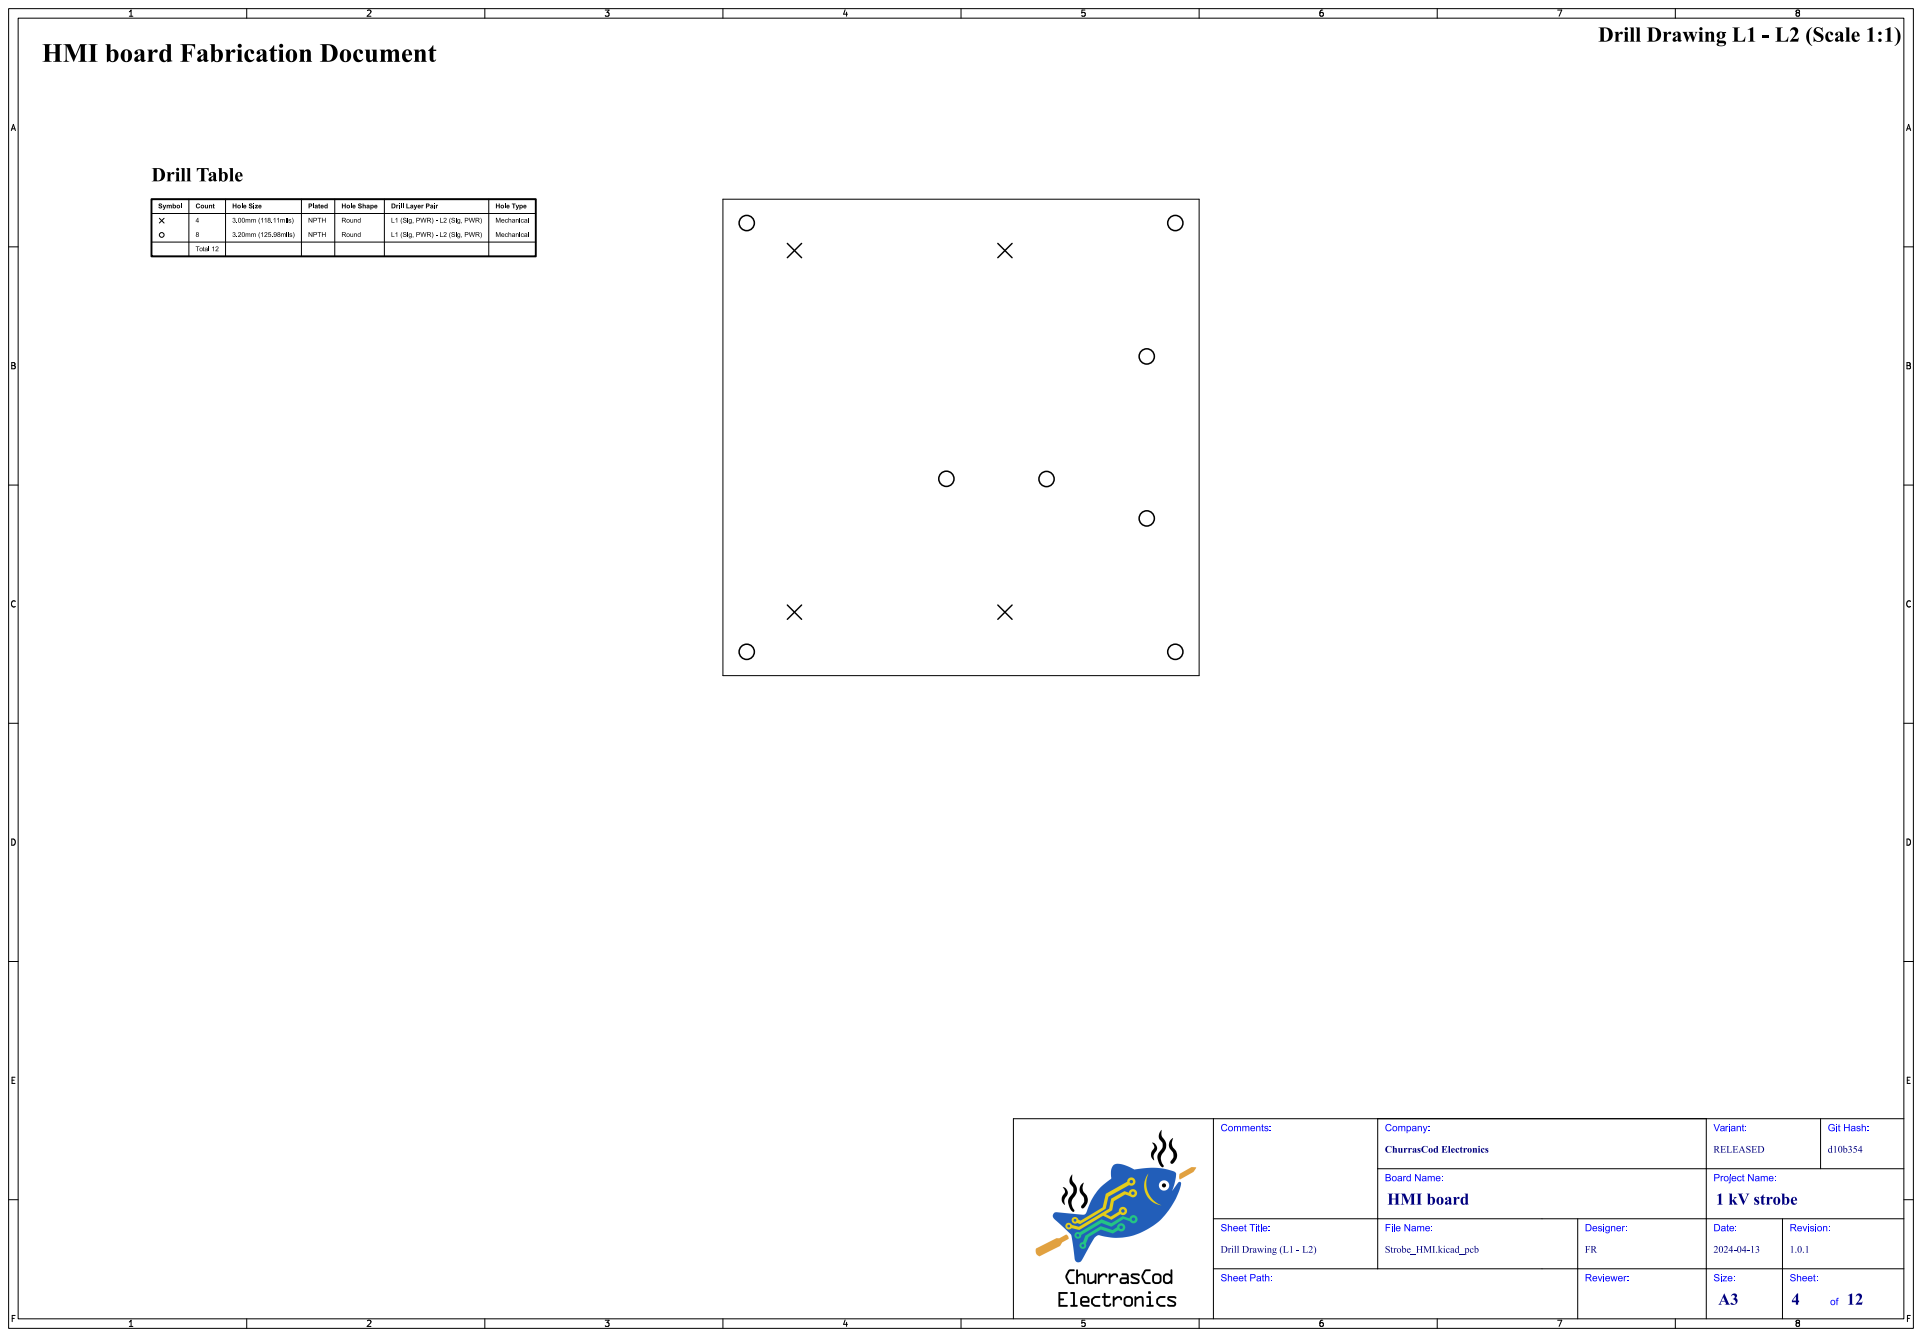
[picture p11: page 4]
Git; Hash:; Comments:; Drill Drawing (L1 - L2); Sheet Title:; File Name:; HMI board; 1 kV strobe; ChurrasCod Electronics; Company:; RELEASED; Variant:; Board Name:; Strobe_HMI.kicad_pcb; Designer:; Project Name:; Date:; Revision:

# Top Test Points (Scale 1:1) HMI board Fabrication Document

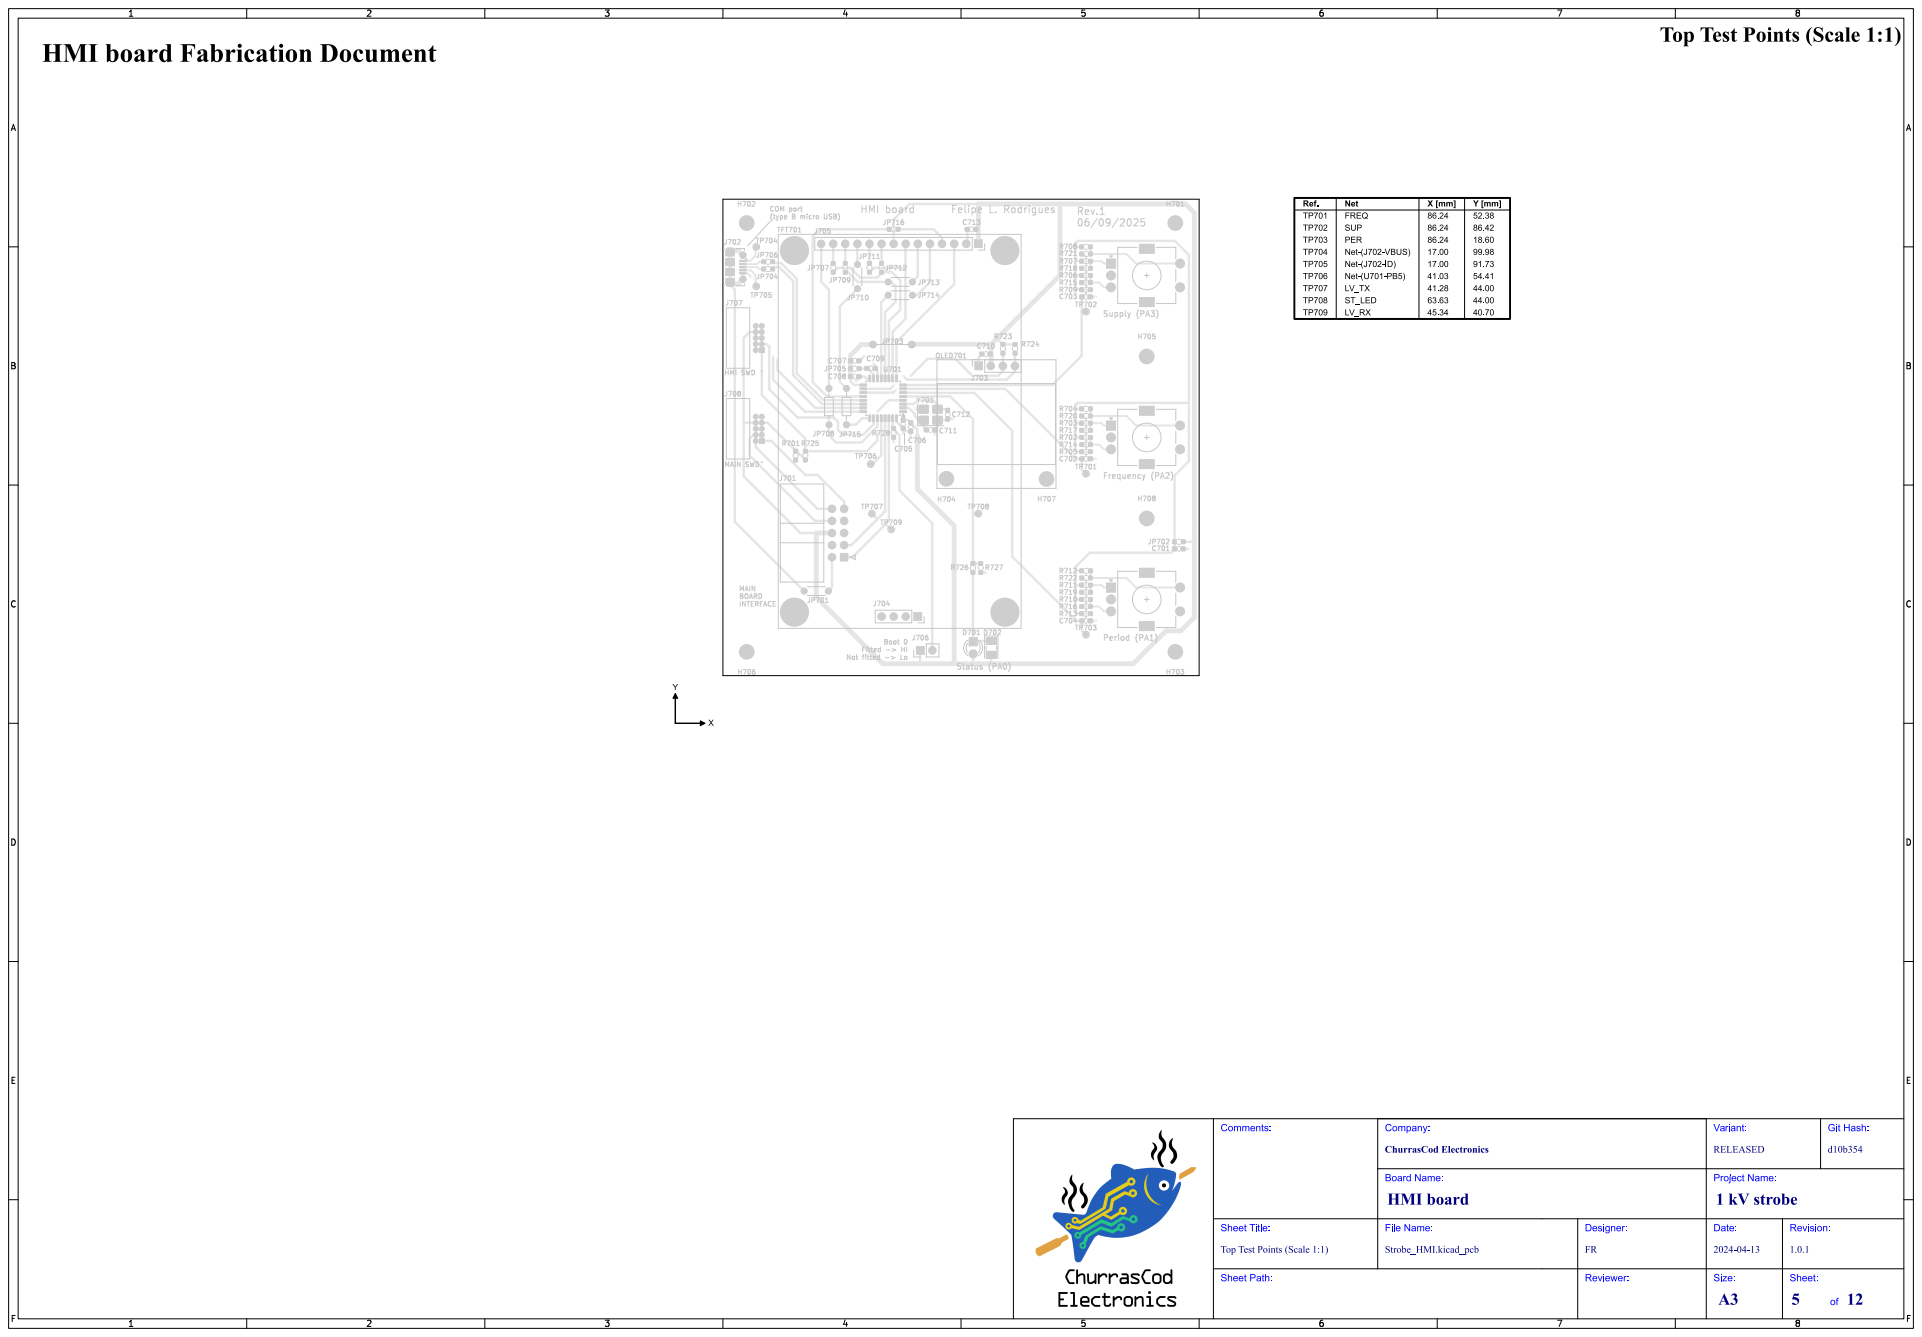
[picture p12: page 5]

Top Test Points (Scale 1:1)

# Bottom Test Points (Scale 1:1) HMI board Fabrication Document

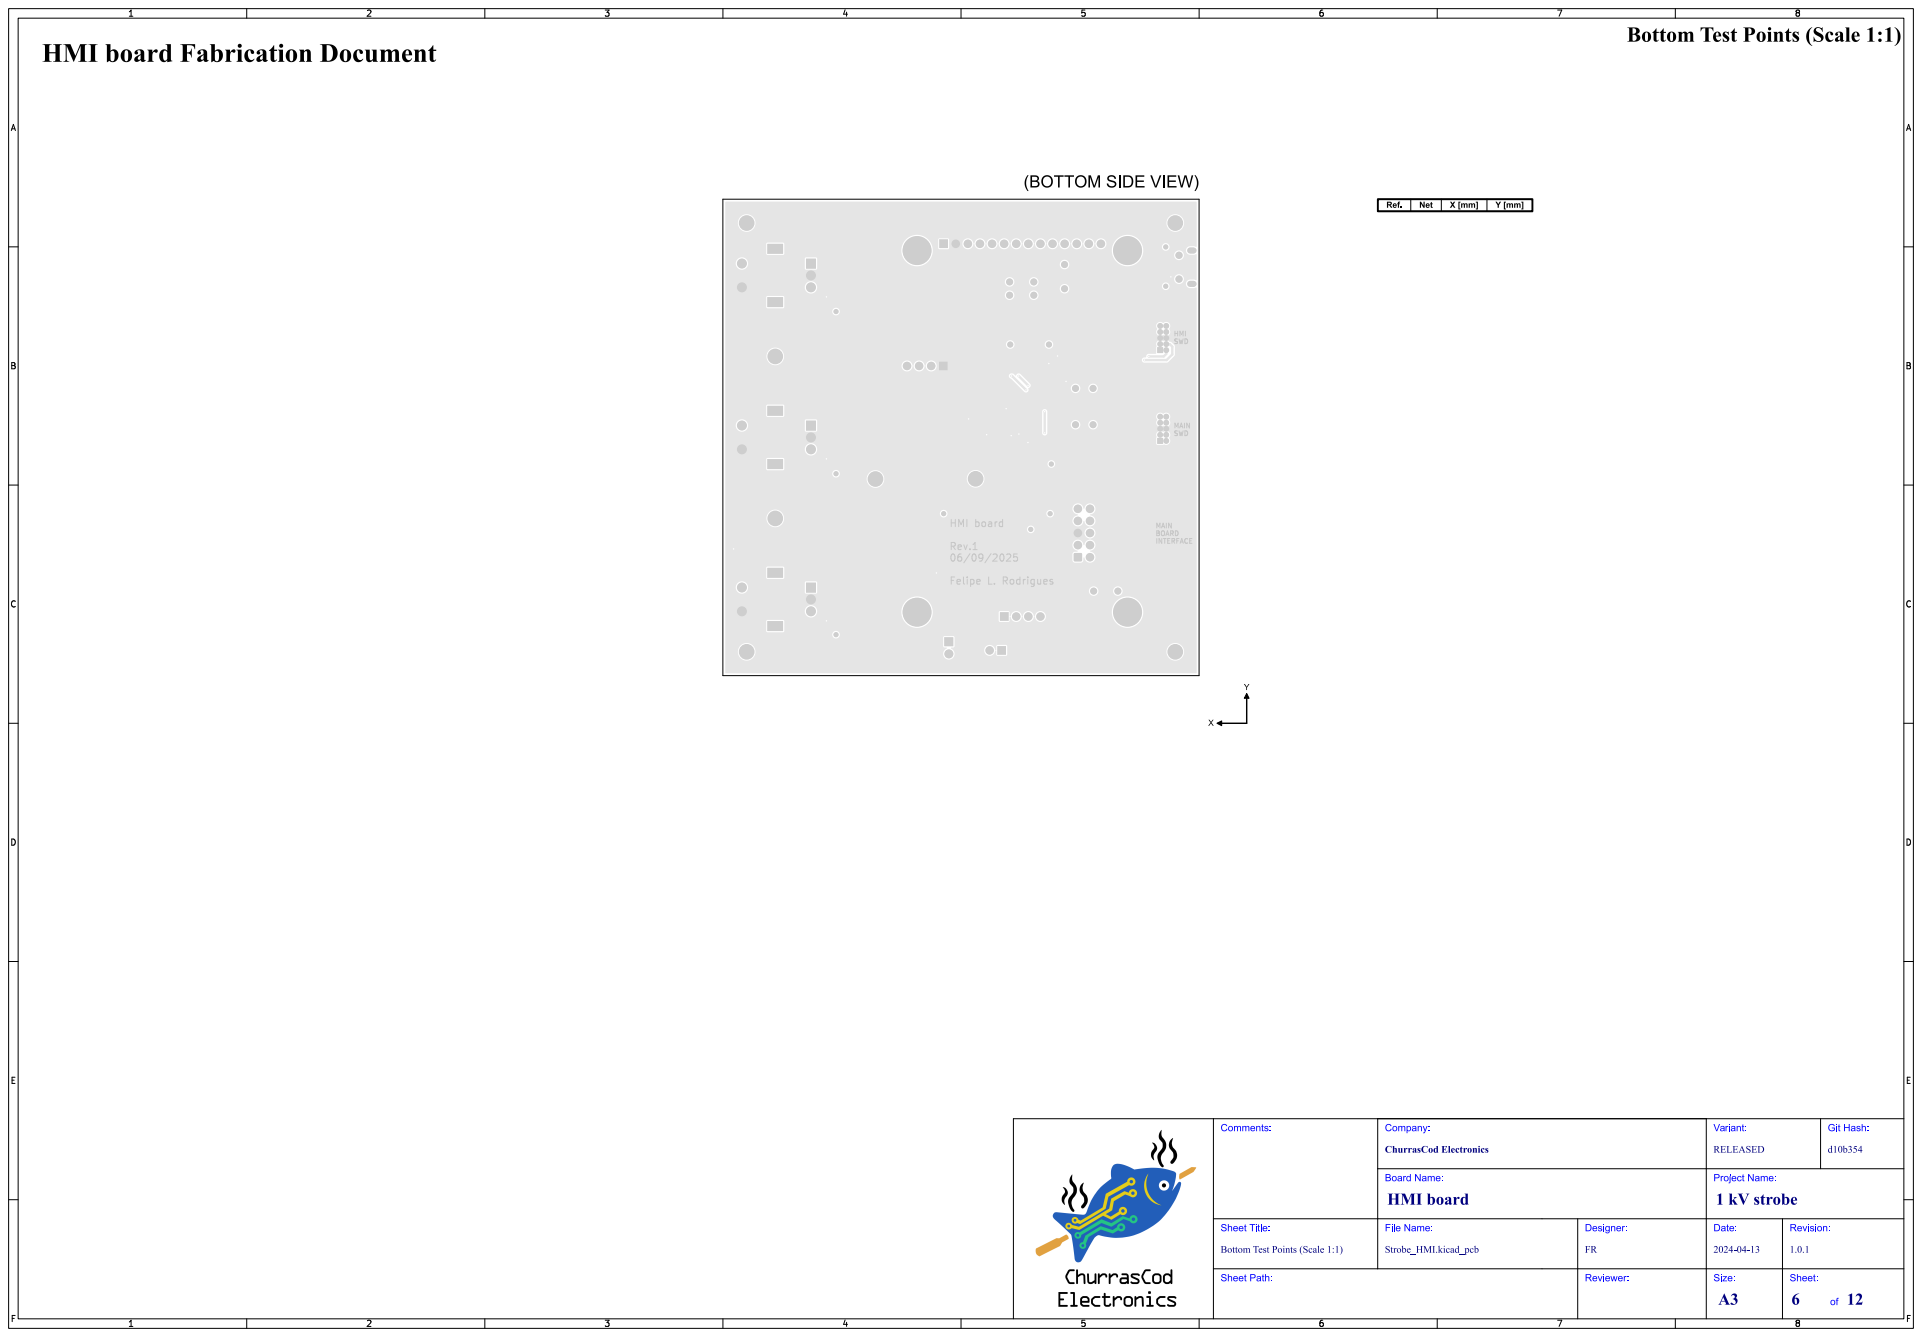
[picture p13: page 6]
Git; Hash:; Comments:; Sheet Title:; File Name:; HMI board; 1 kV strobe; ChurrasCod Electronics; Company:; RELEASED; Variant:; Board Name:; Strobe_HMI.kicad_pcb; Designer:; Project Name:; Date:; Revision:; Felipe; Rodrigues; Rev.1; HMI; board; INTERFACE; BOARD; MAIN; SWD

Bottom Test Points (Scale 1:1)

# L1 (Sig, PWR) (Scale 1:1) HMI board Fabrication Document

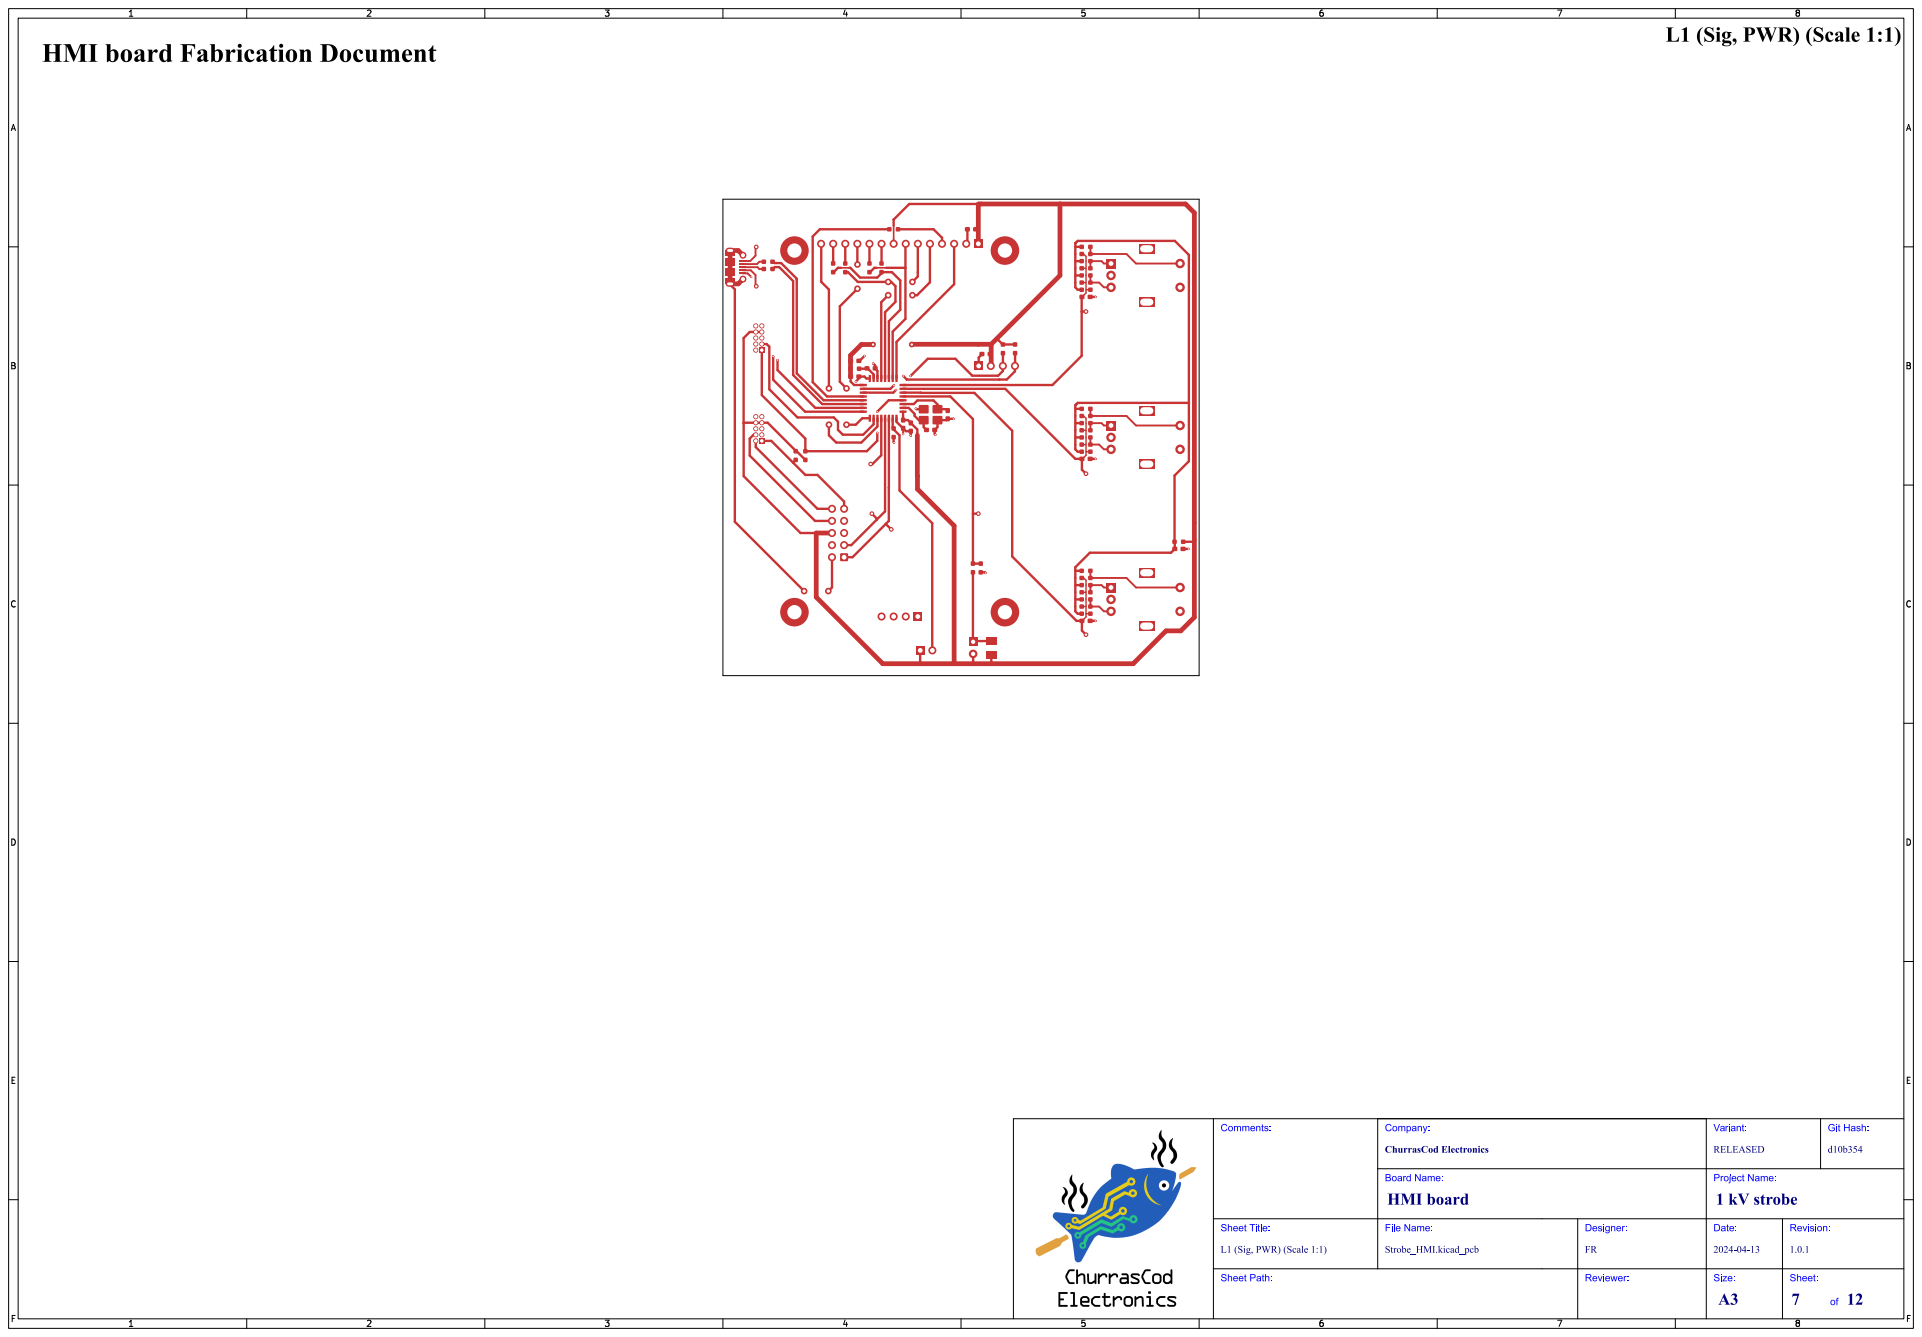
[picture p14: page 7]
Git; Hash:; Comments:; Sheet Title:; File Name:; HMI board; 1 kV strobe; ChurrasCod Electronics; Company:; RELEASED; Variant:; Board Name:; Strobe_HMI.kicad_pcb; Designer:; Project Name:; Date:; Revision:

L1 (Sig, PWR) (Scale 1:1)

# L2 (Sig, PWR) (Scale 1:1) HMI board Fabrication Document

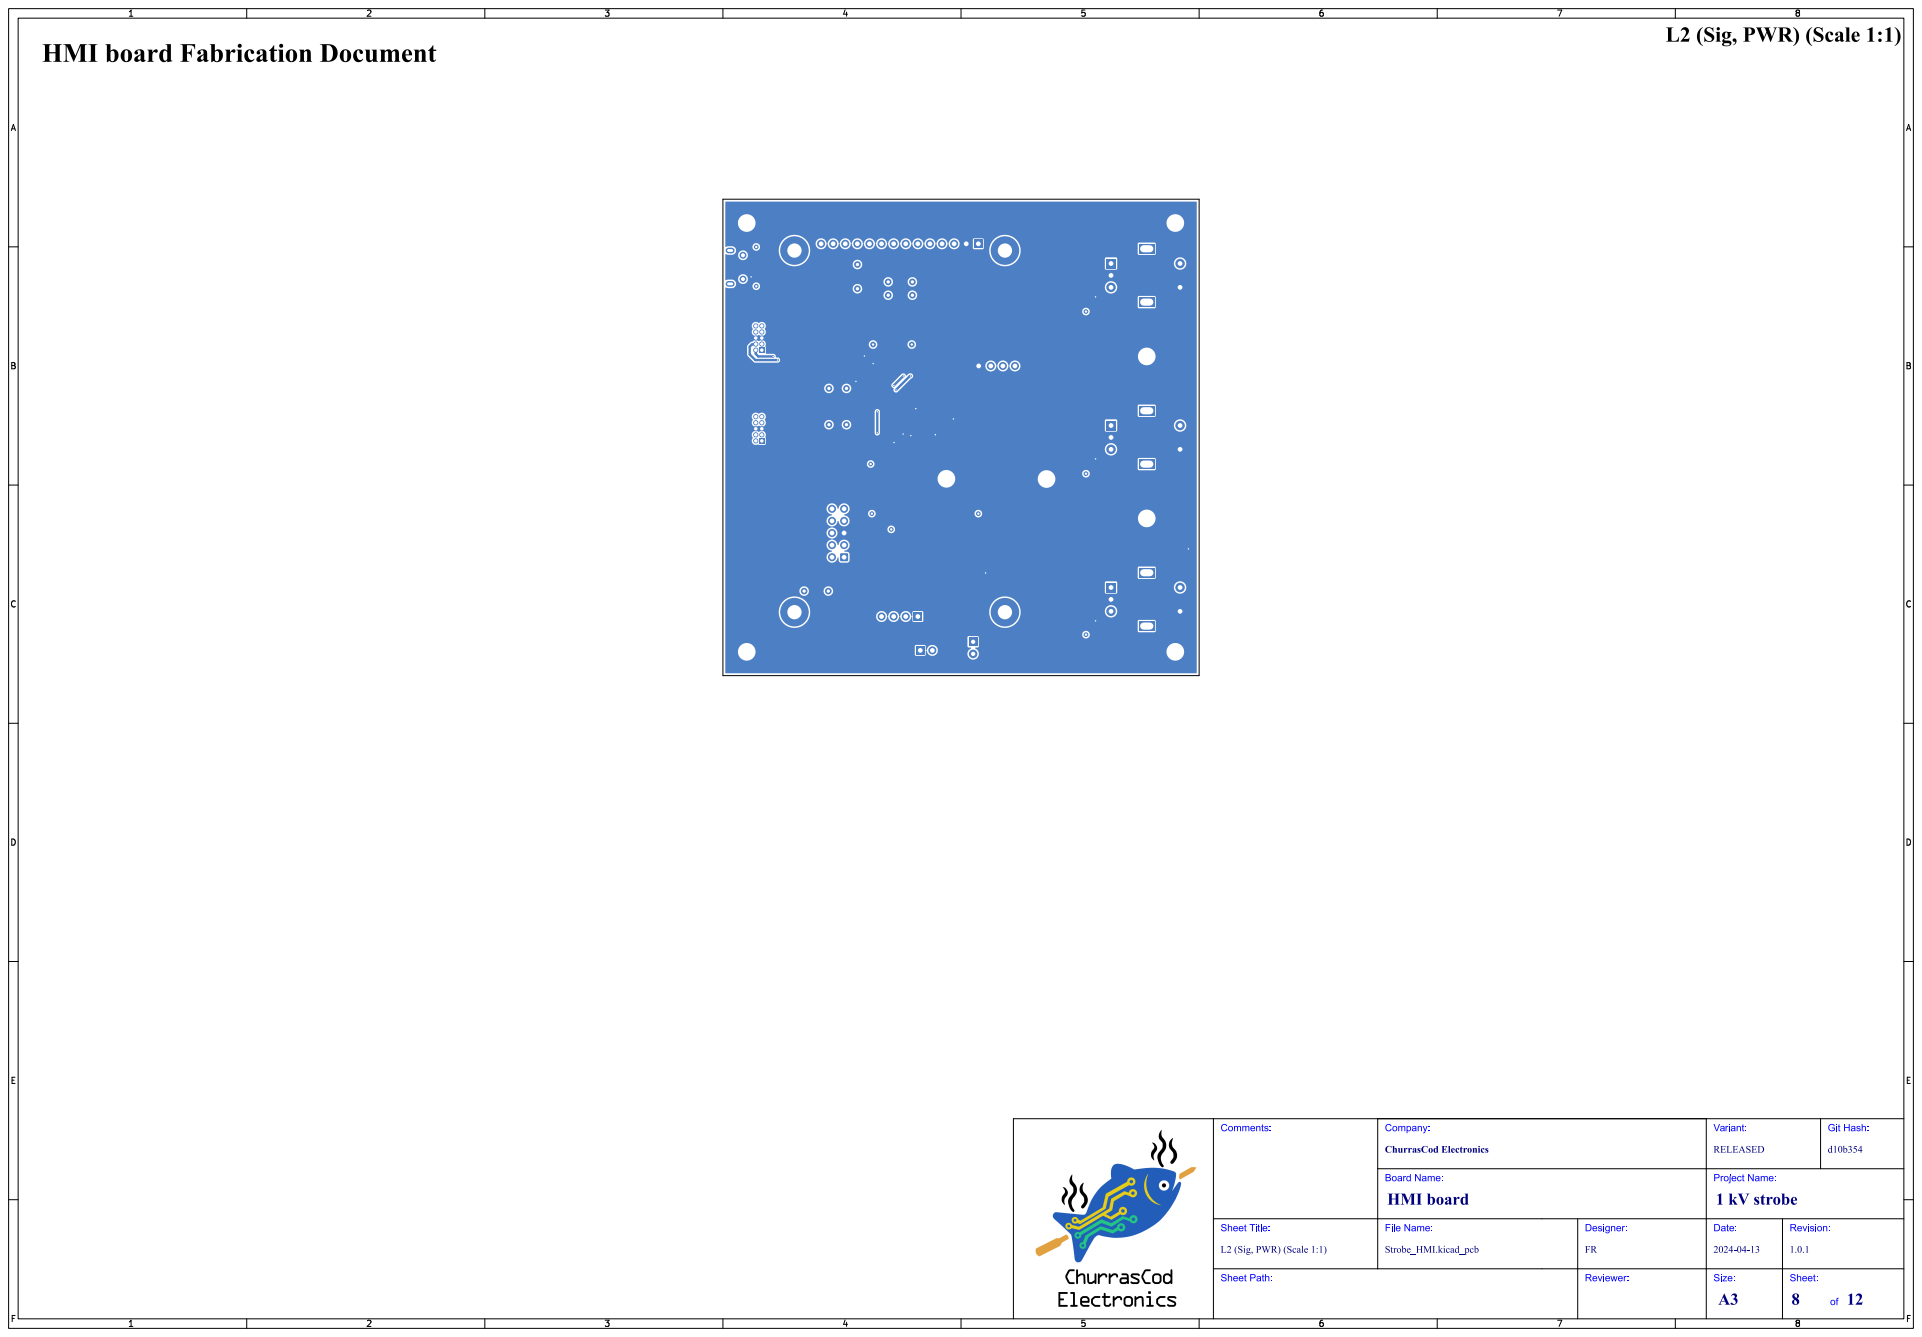
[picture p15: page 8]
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

L2 (Sig, PWR) (Scale 1:1)

# F.Mask (Scale 1:1) HMI board Fabrication Document

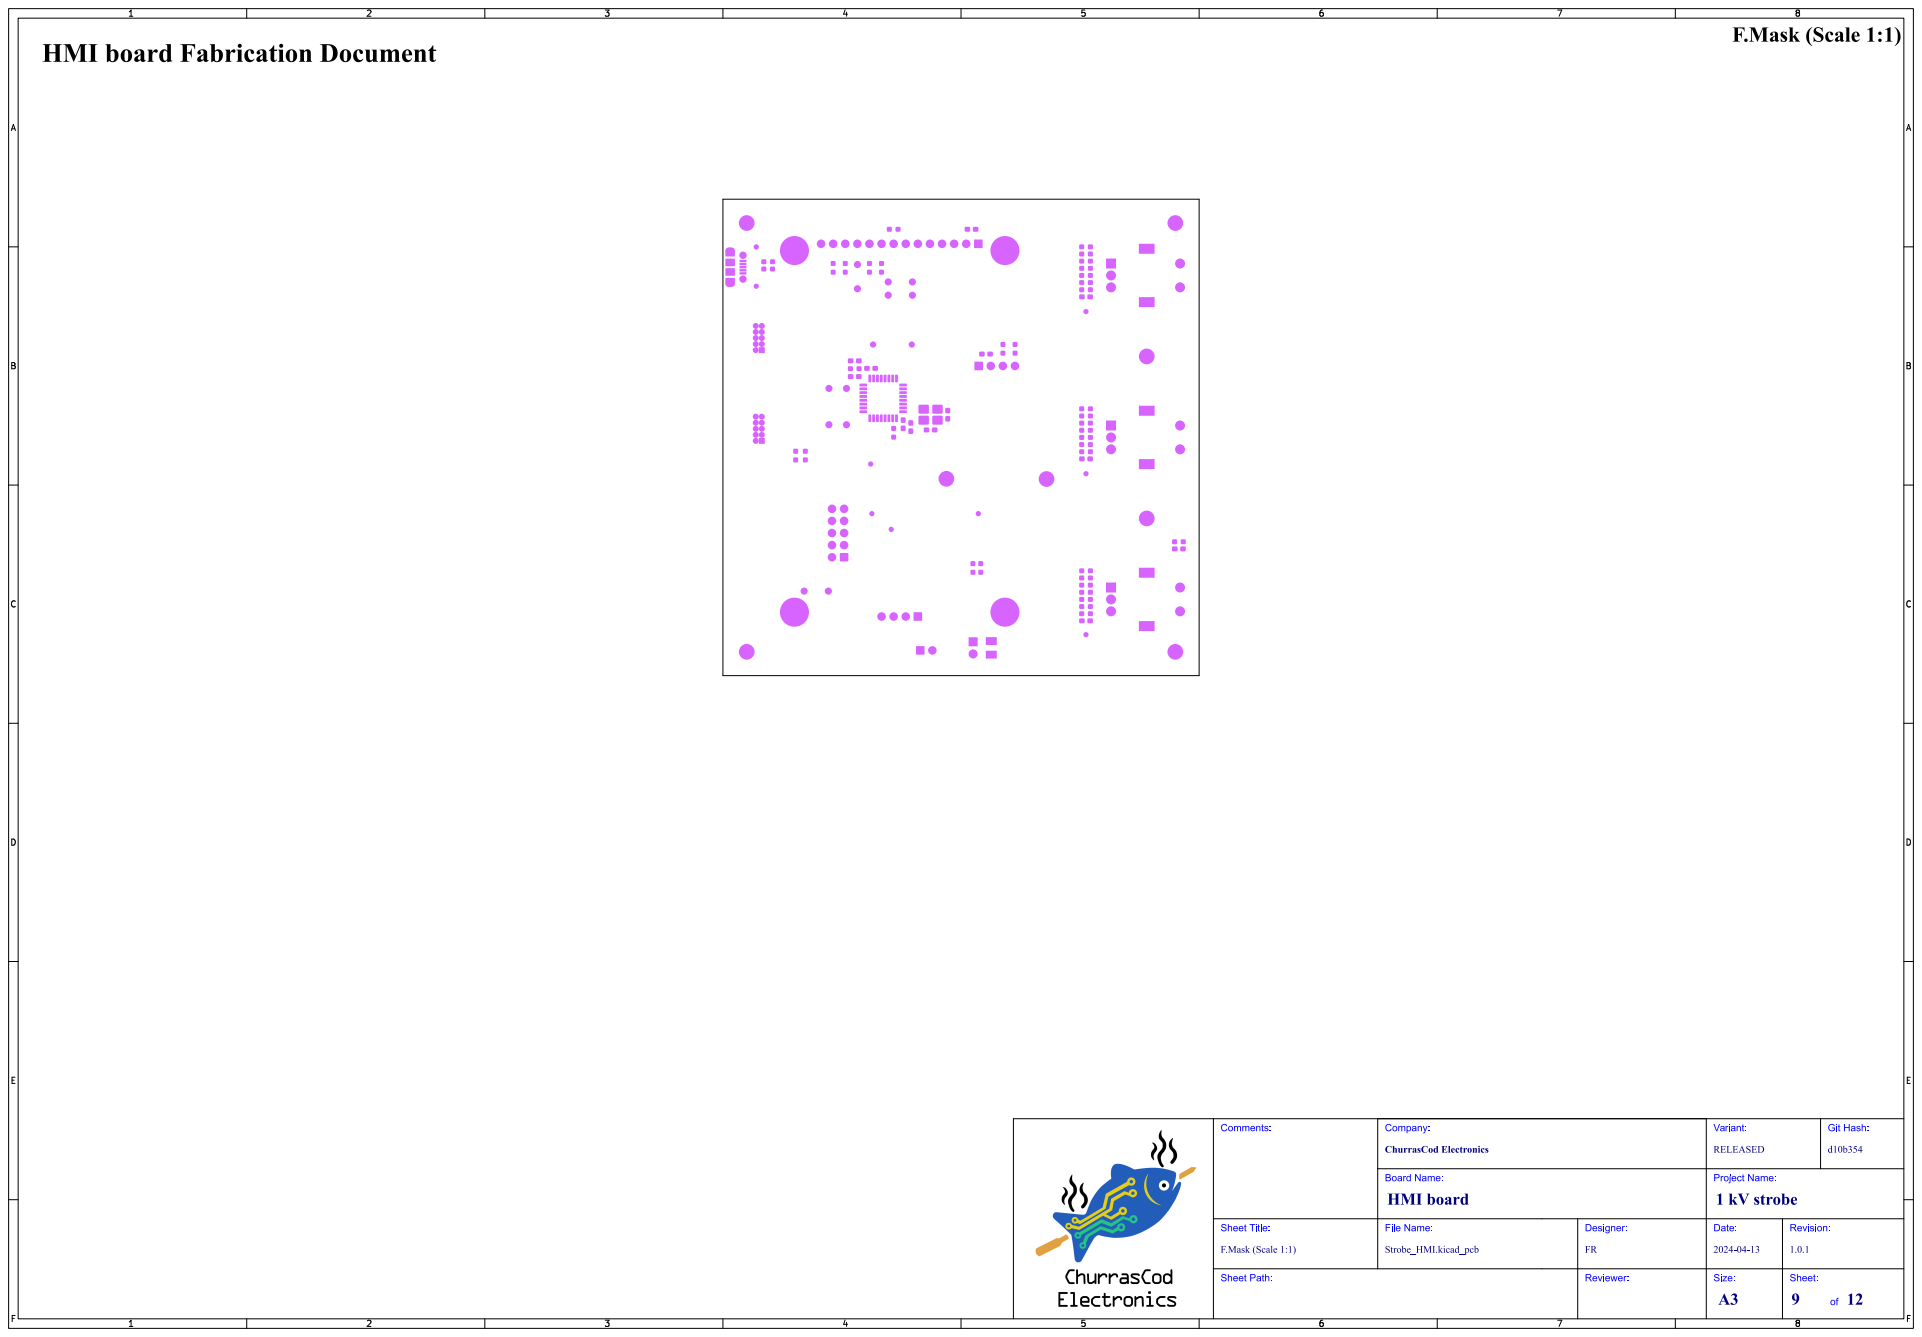
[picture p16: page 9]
Git; Hash:; Comments:; F.Mask (Scale 1:1); Sheet Title:; File Name:; HMI board; 1 kV strobe; ChurrasCod Electronics; Company:; RELEASED; Variant:; Board Name:; Strobe_HMI.kicad_pcb; Designer:; Project Name:; Date:; Revision:

# B.Mask (Scale 1:1) HMI board Fabrication Document

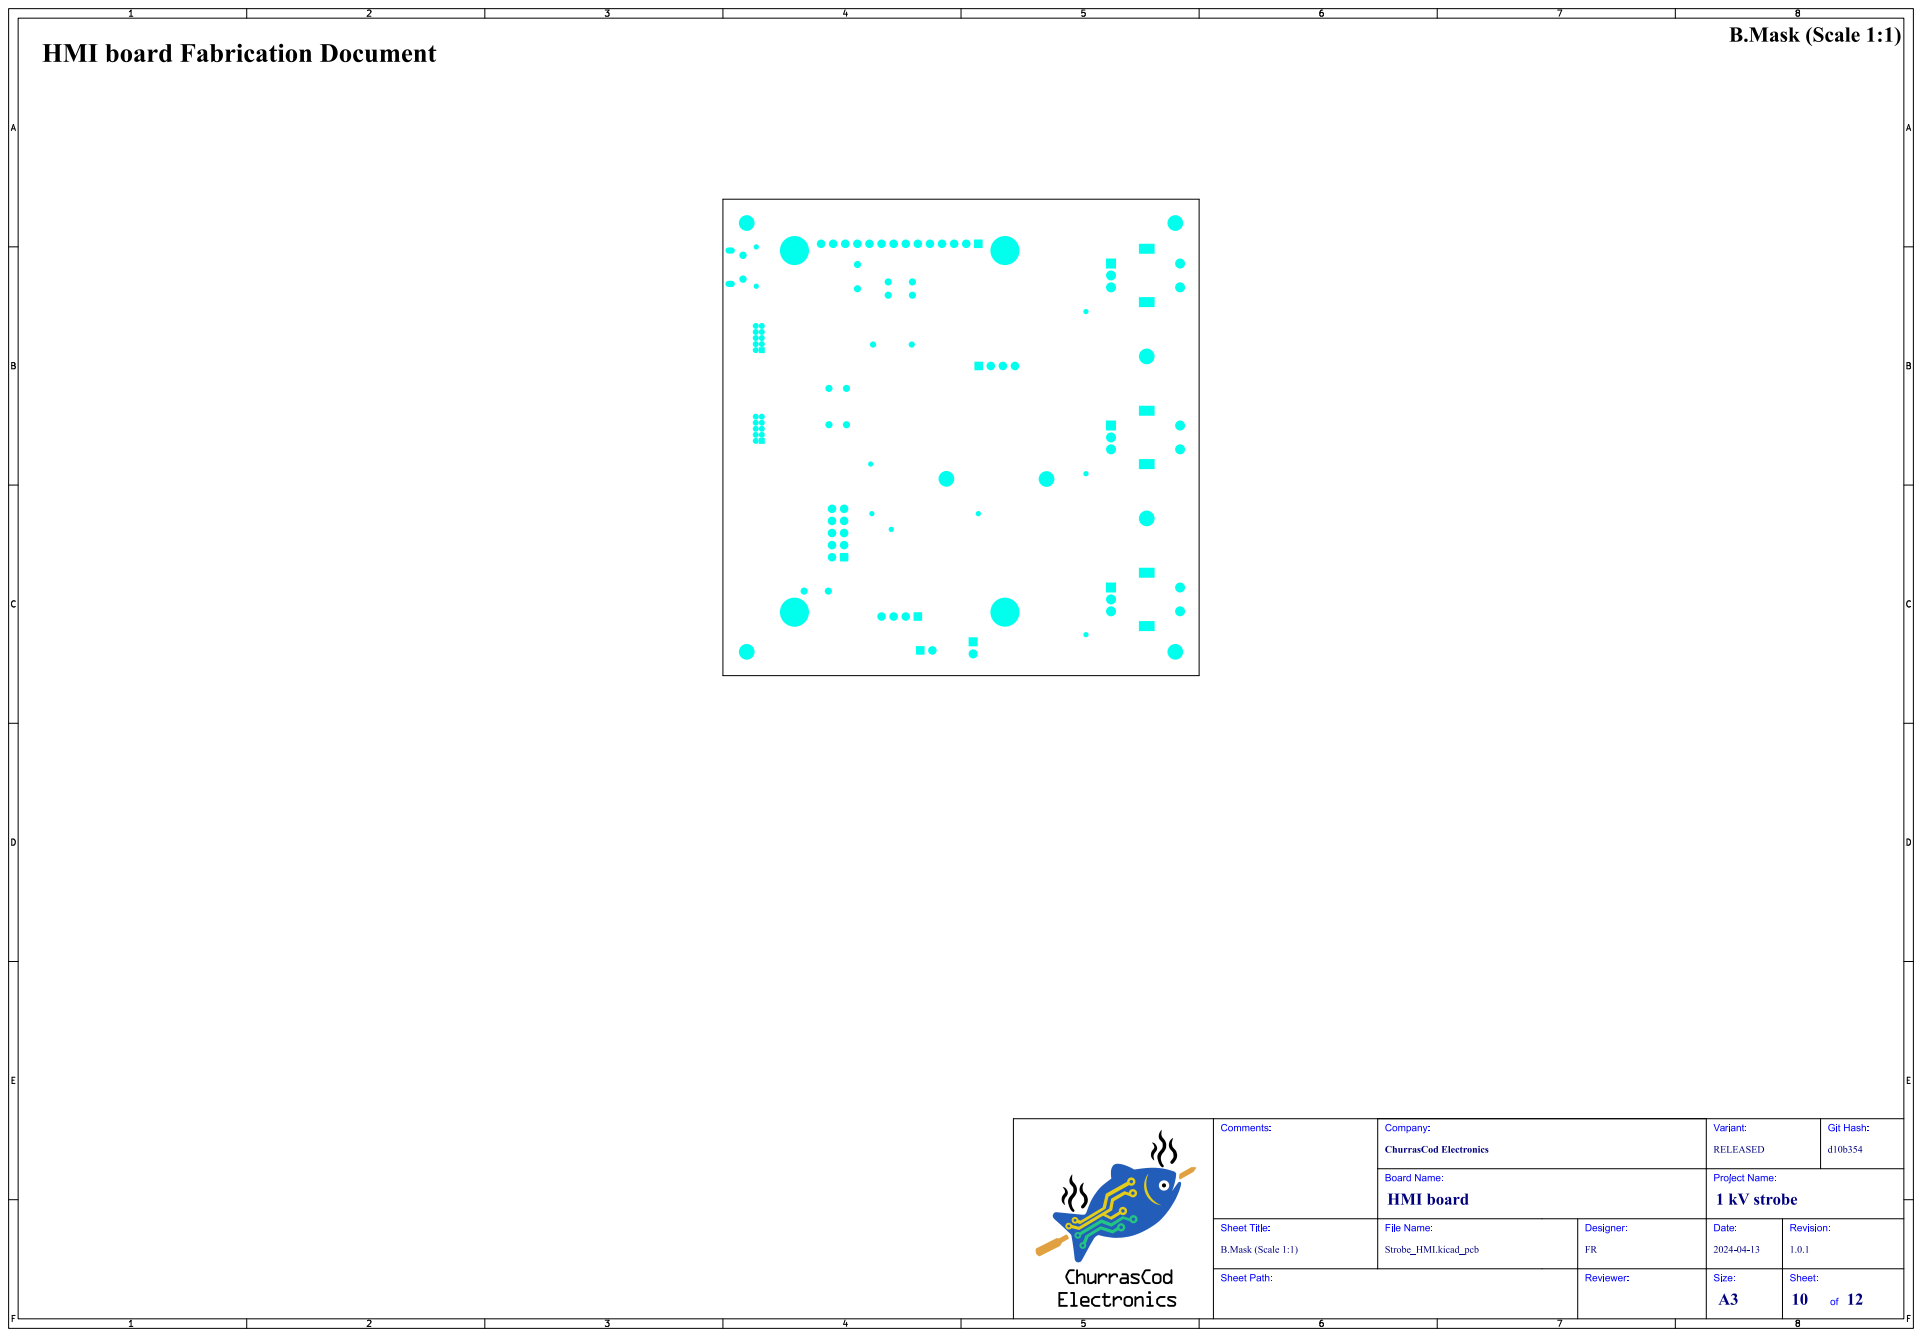
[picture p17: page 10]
Git; Hash:; Comments:; B.Mask (Scale 1:1); Sheet Title:; File Name:; HMI board; 1 kV strobe; ChurrasCod Electronics; Company:; RELEASED; Variant:; Board Name:; Strobe_HMI.kicad_pcb; Designer:; Project Name:; Date:; Revision:

# F.Silkscreen (Scale 1:1) HMI board Fabrication Document

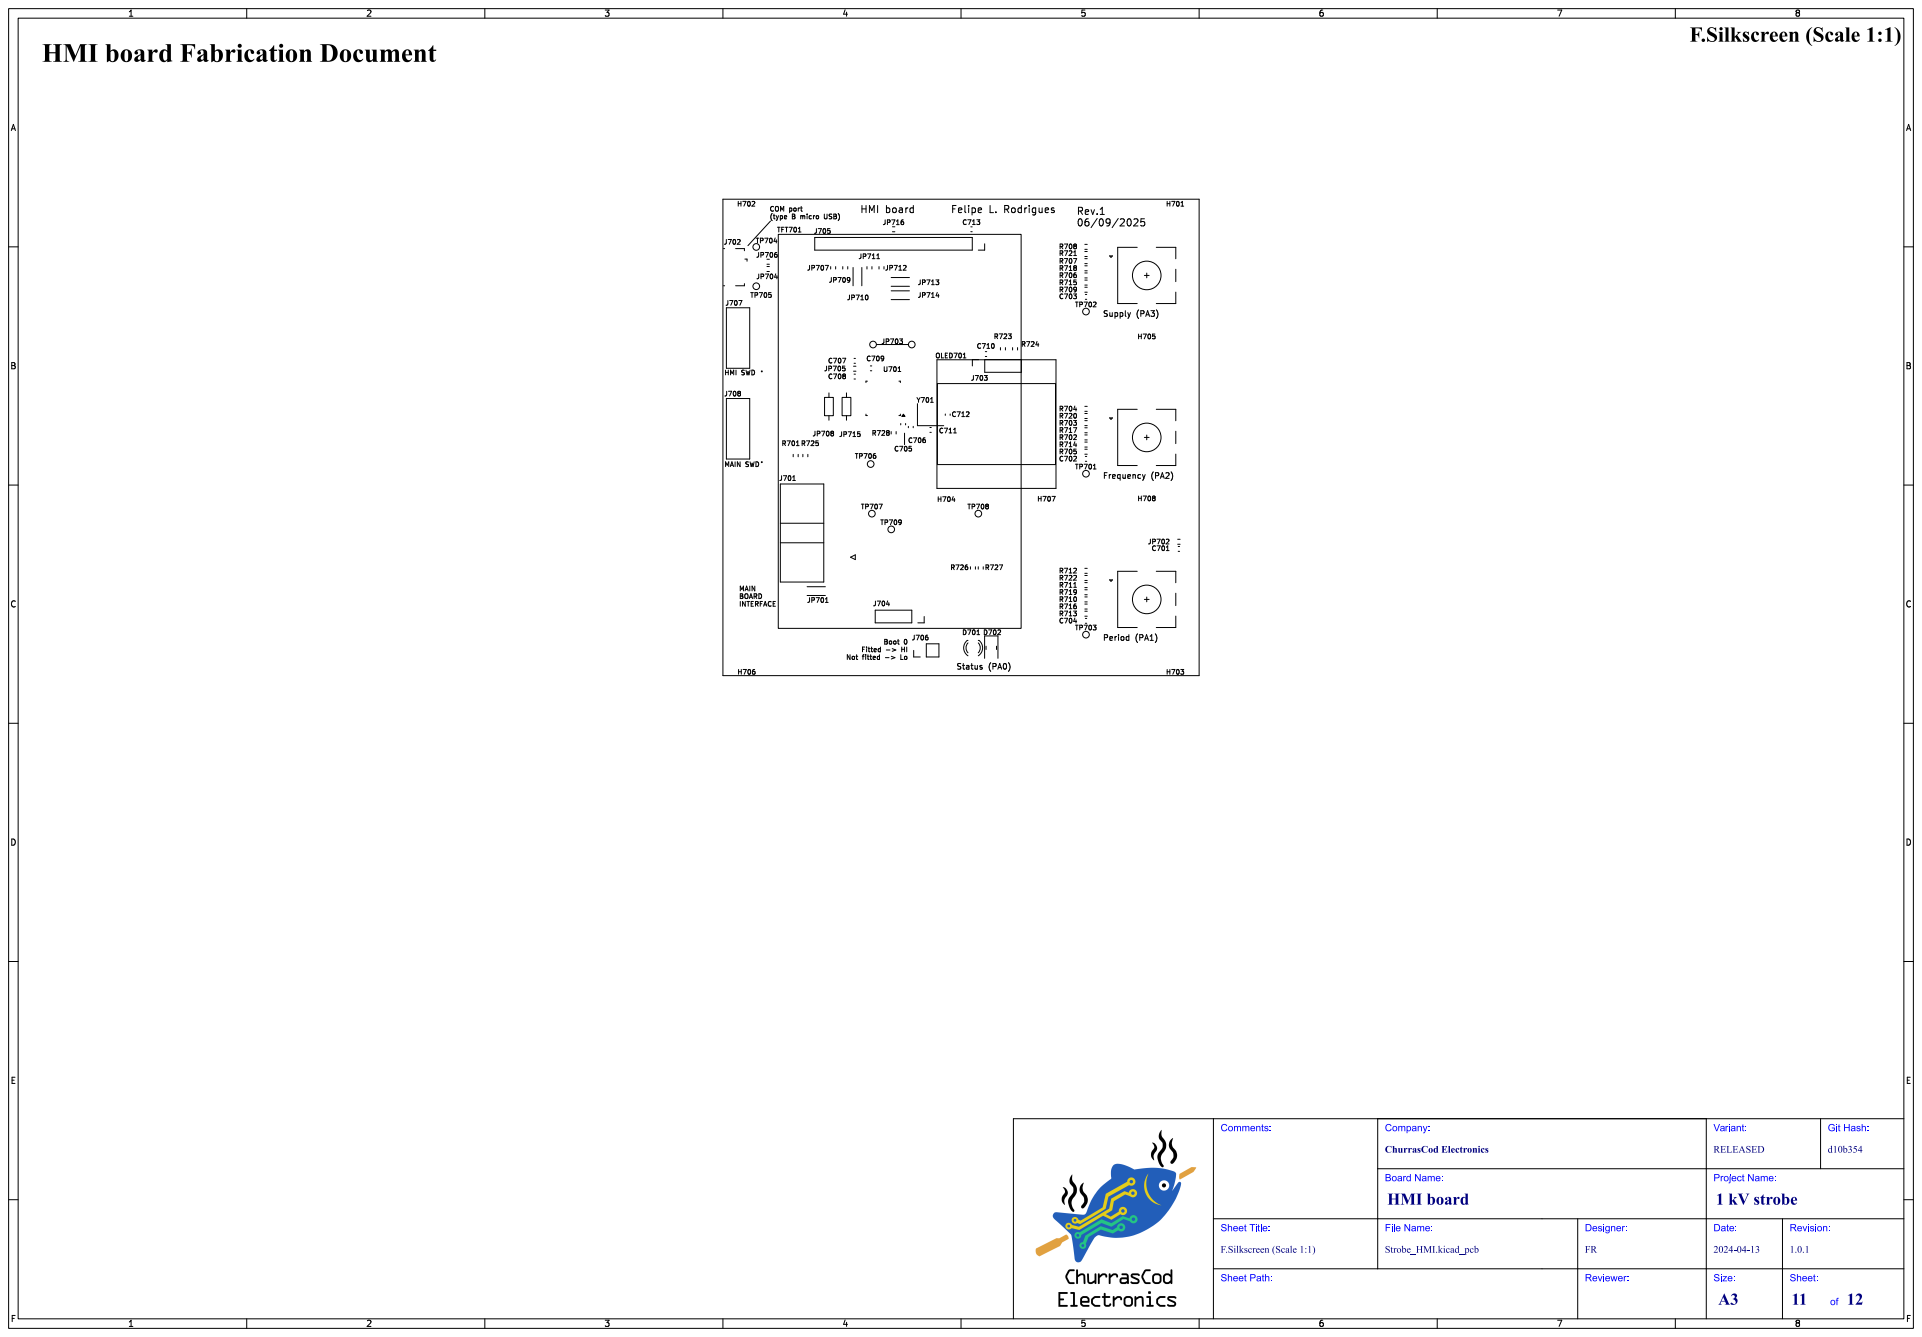
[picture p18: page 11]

# B.Silkscreen (Scale 1:1) HMI board Fabrication Document

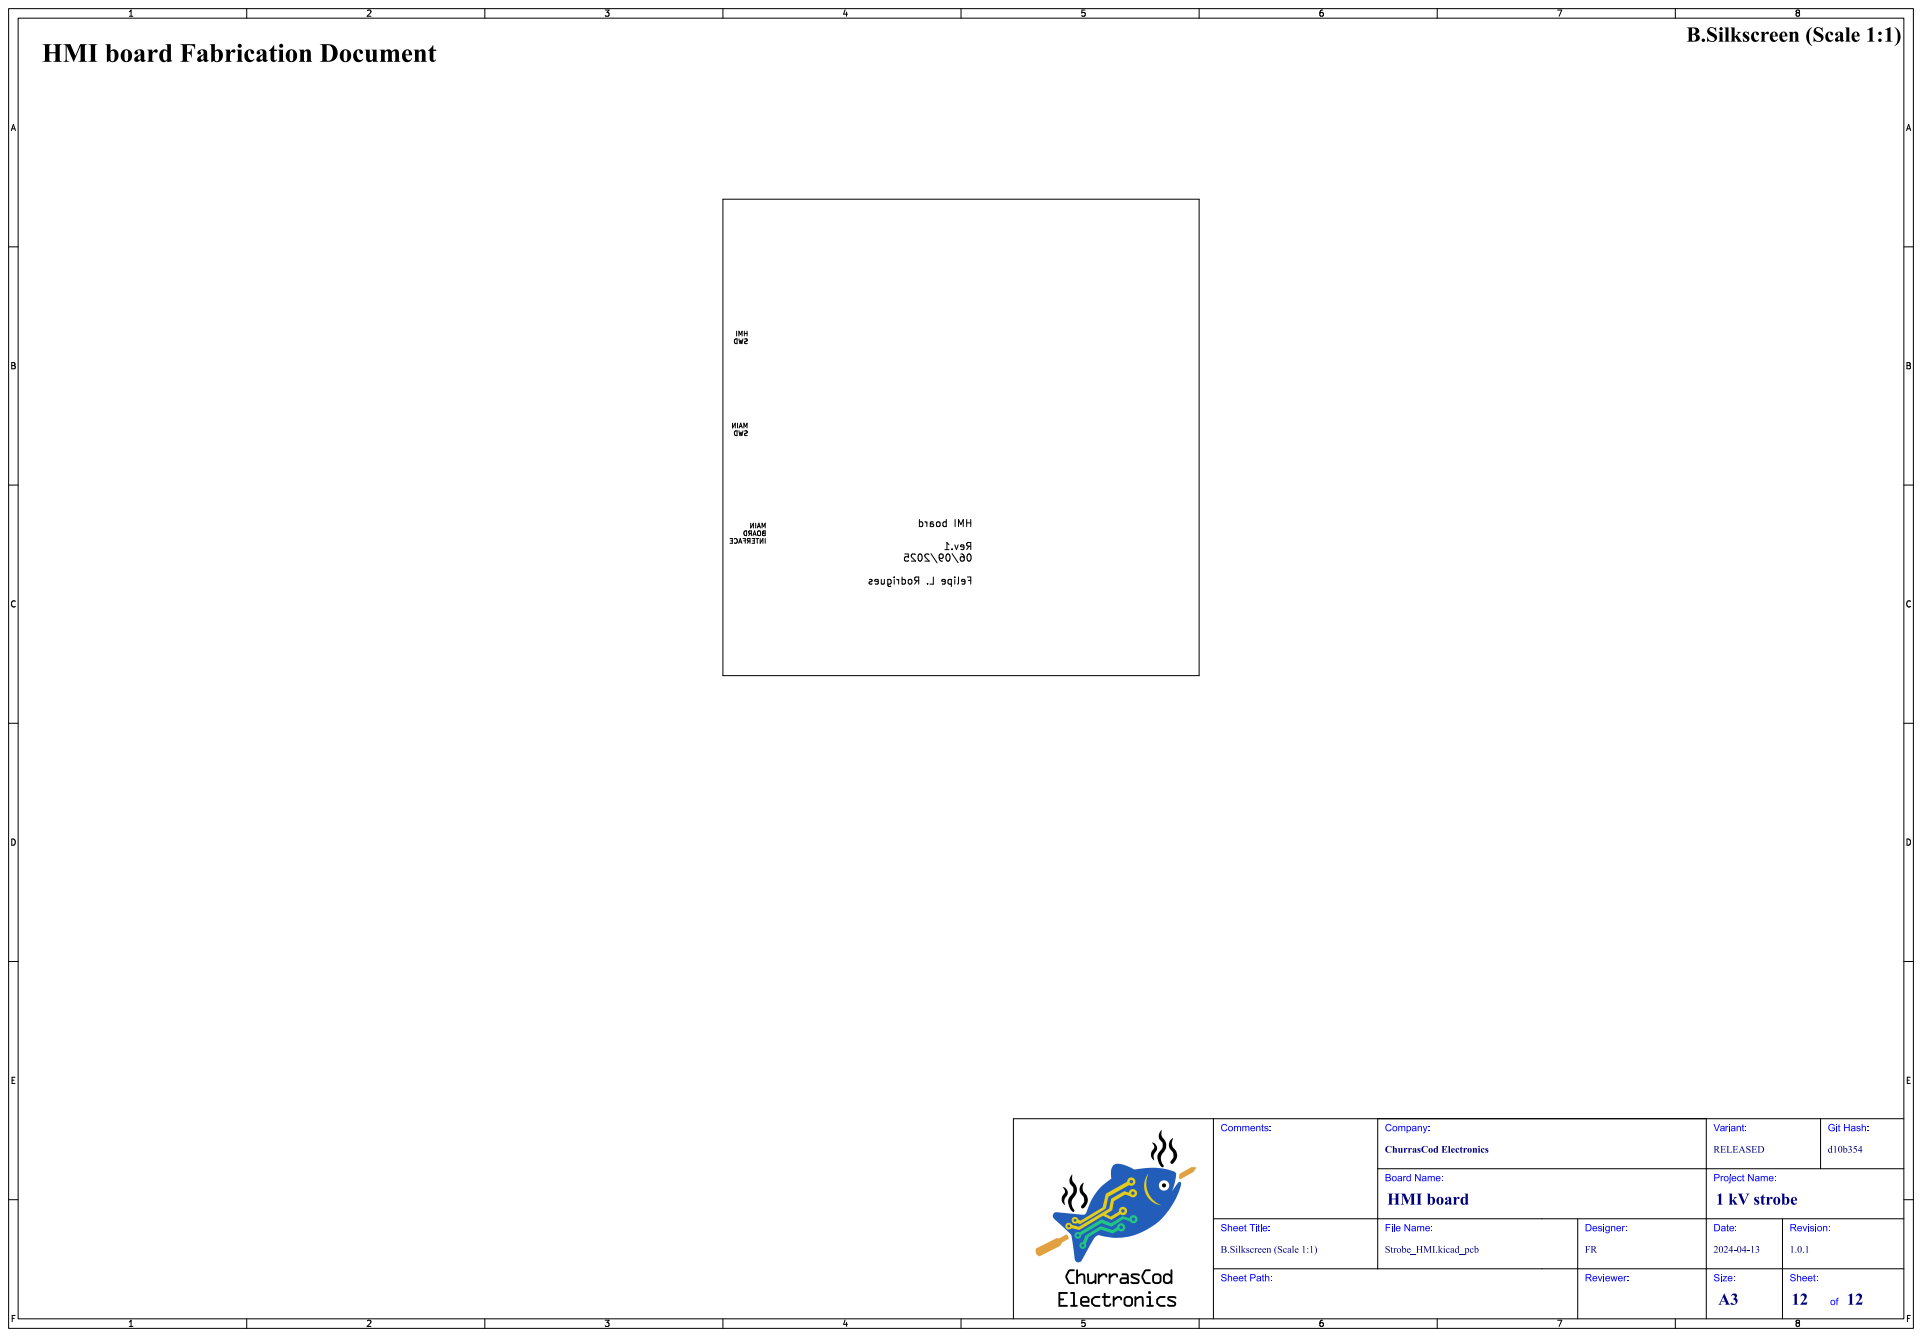
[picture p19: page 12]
Git; Hash:; Comments:; B.Silkscreen (Scale 1:1); Sheet Title:; File Name:; HMI board; 1 kV strobe; ChurrasCod Electronics; Company:; RELEASED; Variant:; Board Name:; Strobe_HMI.kicad_pcb; Designer:; Project Name:; Date:; Revision:; Felipe L. Rodrigues; Rev.1; INTERFACE; BOARD; MAIN; SWD; HMI

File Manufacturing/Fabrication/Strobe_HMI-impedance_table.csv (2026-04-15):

Transmission Line | Impedance [ohms] | Tolerance [ohms] | Layer | Trace Width [mm] | Gap [mm] | Ref. Layers
Edge-Coupled Coated Microstrip | 100 | ±10 % | L1 | 0.2032 | 0.28 | L2

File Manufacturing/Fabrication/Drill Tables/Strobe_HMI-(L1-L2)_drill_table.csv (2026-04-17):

Count | Hole Size | Plated | Hole Shape | Drill Layer Pair | Hole Type
23 | 0.30mm (11.81mils) | PTH | Round | L1 (Sig, PWR) - L2 (Sig, PWR) | Via
11 | 0.50mm (19.69mils) | PTH | Round | L1 (Sig, PWR) - L2 (Sig, PWR) | Pad
2 | 0.60mm (23.62mils) | PTH | Slot | L1 (Sig, PWR) - L2 (Sig, PWR) | Pad
12 | 0.70mm (27.56mils) | PTH | Round | L1 (Sig, PWR) - L2 (Sig, PWR) | Pad
20 | 0.74mm (29.13mils) | PTH | Round | L1 (Sig, PWR) - L2 (Sig, PWR) | Pad
2 | 0.85mm (33.46mils) | PTH | Round | L1 (Sig, PWR) - L2 (Sig, PWR) | Pad
2 | 0.90mm (35.43mils) | PTH | Round | L1 (Sig, PWR) - L2 (Sig, PWR) | Pad
49 | 1.00mm (39.37mils) | PTH | Round | L1 (Sig, PWR) - L2 (Sig, PWR) | Pad
6 | 1.50mm (59.06mils) | PTH | Slot | L1 (Sig, PWR) - L2 (Sig, PWR) | Pad
Total 127

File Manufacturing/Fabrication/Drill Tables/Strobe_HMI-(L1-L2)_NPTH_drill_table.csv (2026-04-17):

Count | Hole Size | Plated | Hole Shape | Drill Layer Pair | Hole Type
4 | 3.00mm (118.11mils) | NPTH | Round | L1 (Sig, PWR) - L2 (Sig, PWR) | Mechanical
8 | 3.20mm (125.98mils) | NPTH | Round | L1 (Sig, PWR) - L2 (Sig, PWR) | Mechanical
Total 12

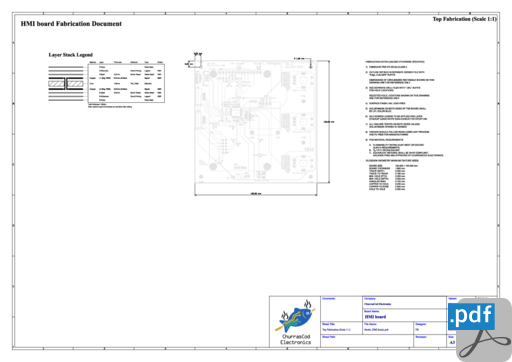
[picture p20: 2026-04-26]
HTML/images/cat_pdf_fabrication_Strobe_HMI-fabrication.png

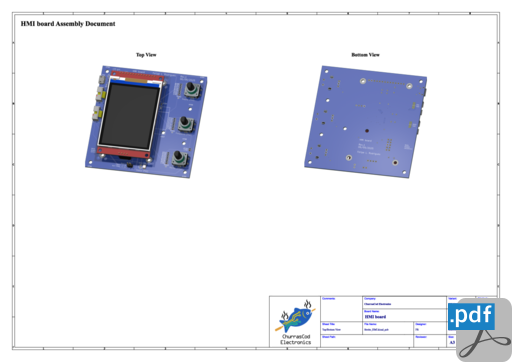
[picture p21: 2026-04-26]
HTML/images/cat_pdf_assembly_Strobe_HMI-assembly.png

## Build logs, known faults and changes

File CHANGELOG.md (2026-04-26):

# Changelog

## [Unreleased]

## [1.0.1] - 2026-04-26

### Moved source code to a separate repository

## [1.0.0] - 2026-04-19

### Migrated existing project to template (KDT)

[Unreleased]: https://github.com/FLRHW/Strobe_HMI/compare/1.0.1...HEAD

[1.0.1]: https://github.com/FLRHW/Strobe_HMI/compare/1.0.0...1.0.1

[1.0.0]: https://github.com/FLRHW/Strobe_HMI/compare/76633c783eb9bcb4bb5eb69d7325bc9ccd6dd227...1.0.0

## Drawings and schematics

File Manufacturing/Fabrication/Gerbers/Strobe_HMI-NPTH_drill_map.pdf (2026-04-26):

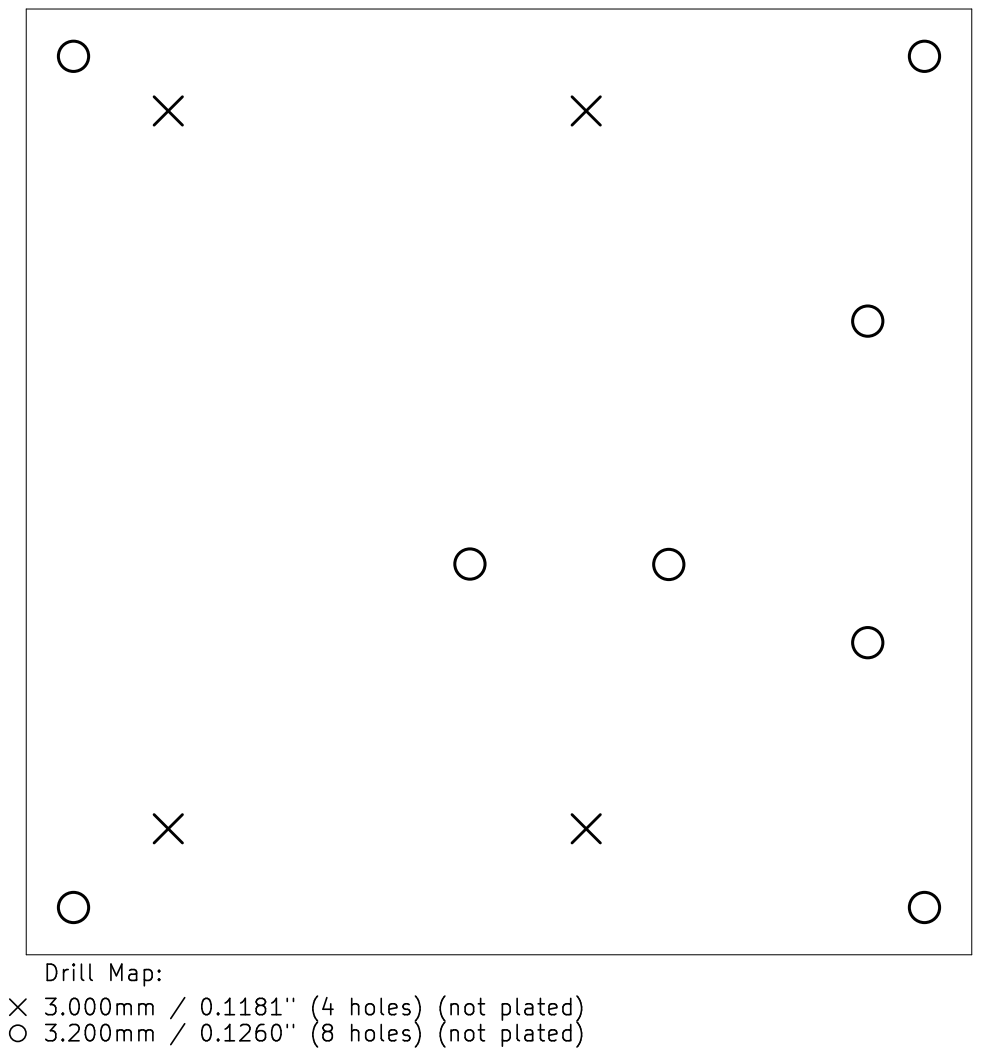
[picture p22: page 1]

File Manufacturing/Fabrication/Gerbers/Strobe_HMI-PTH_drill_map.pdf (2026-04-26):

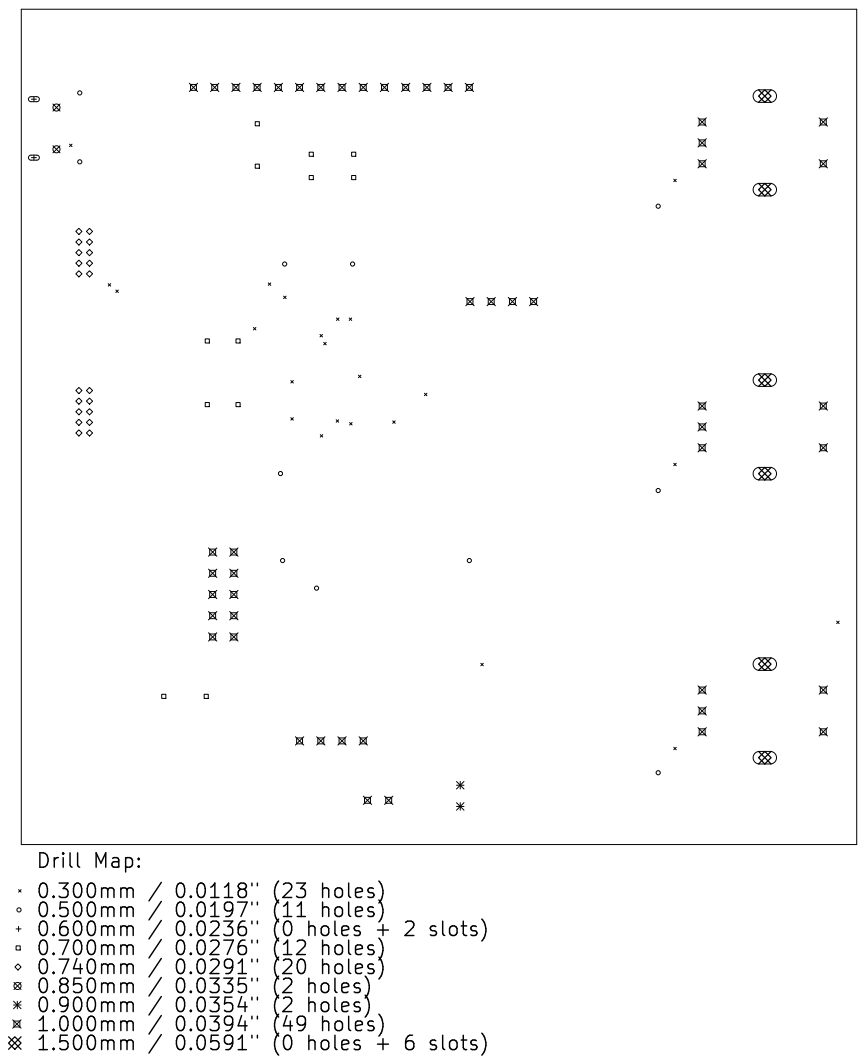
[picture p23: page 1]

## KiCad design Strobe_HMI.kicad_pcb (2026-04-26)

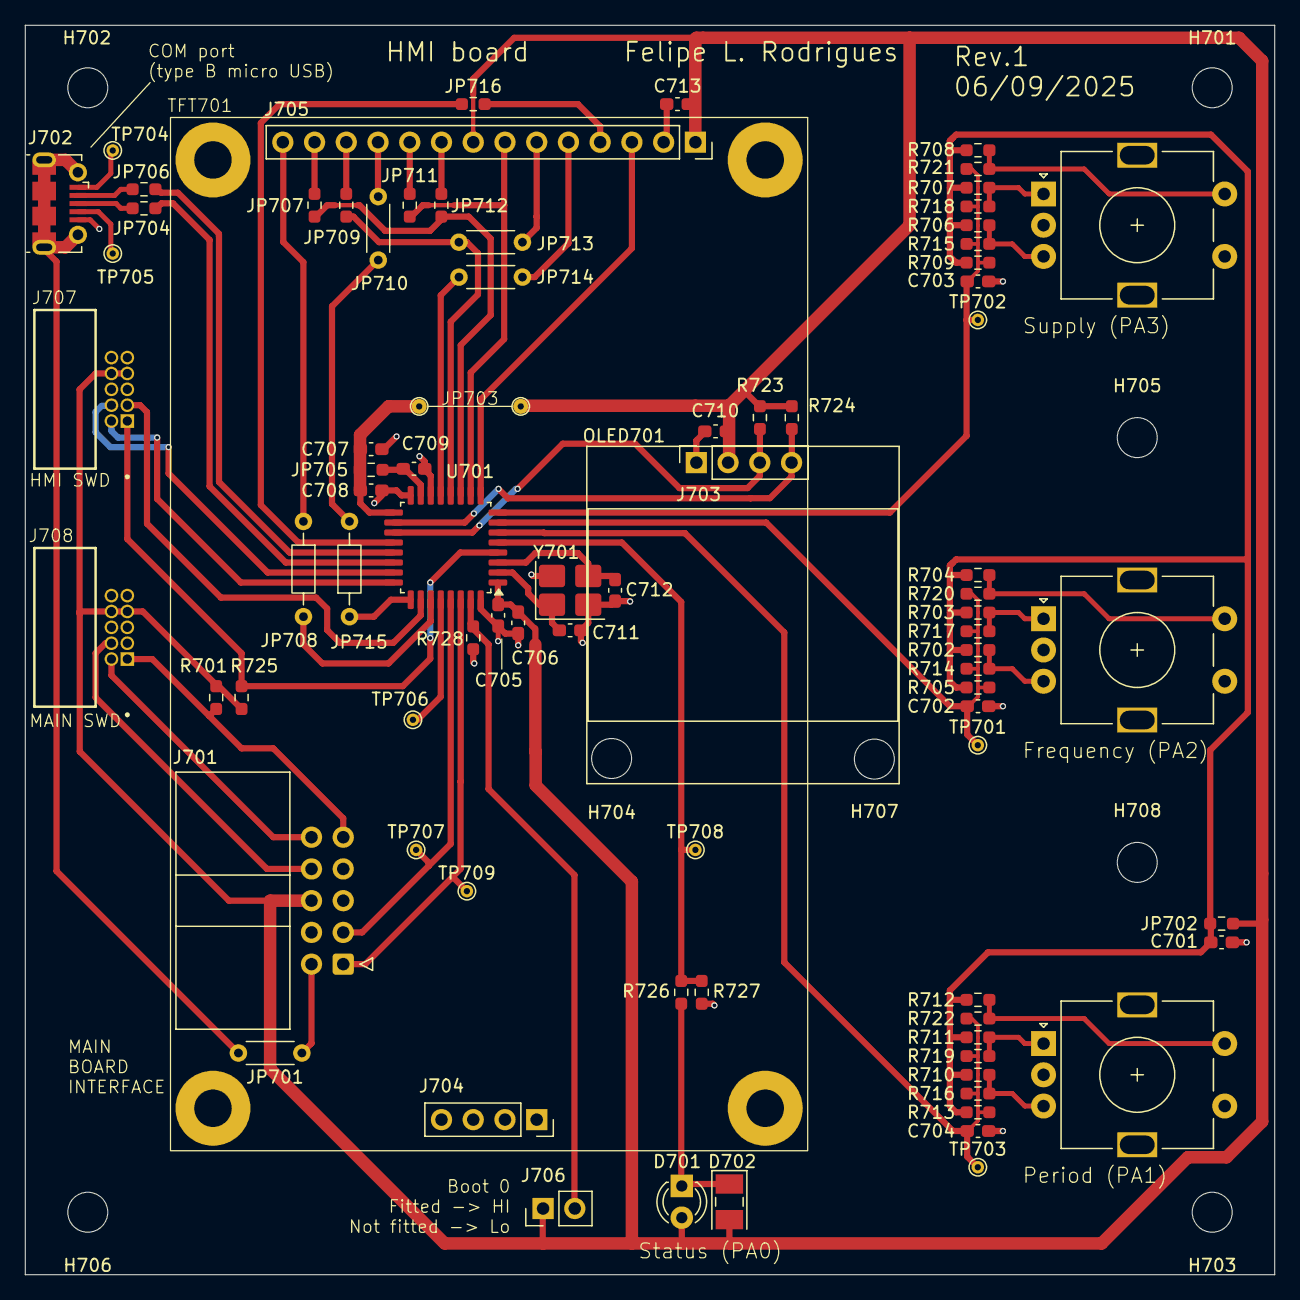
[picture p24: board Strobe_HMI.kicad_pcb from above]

Board: 2 copper layers, 100.0 x 100.0 mm, 91 parts (0 on the bottom side), 60 nets.

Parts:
C701, C702, C703, C704, C705, C708, C709, C710, C713: 100n; C_0603_1608Metric_Pad1.08x0.95mm_HandSolder
C706, C707: 1u; C_0603_1608Metric_Pad1.08x0.95mm_HandSolder
C711, C712: 22p; C_0603_1608Metric_Pad1.08x0.95mm_HandSolder
D701: LED; LED_D3.0mm
D702: LED; LED_PLCC-2_3x2mm_KA
H701, H702, H703, H704, H705, H706, H707, H708: MountingHole; MountingHole_3.2mm_M3
J701: ZHOURI DC3; IDC-Header_2x05_P2.54mm_Horizontal
J702: 1050171001 Micro Type B; USB_Micro-B_Molex-105017-0001
J703, J704: Conn_01x04_Pin; PinSocket_1x04_P2.54mm_Vertical
J705: Conn_01x14_Pin; PinSocket_1x14_P2.54mm_Vertical
J706: Header; PinHeader_1x02_P2.54mm_Vertical
J707, J708: HX JN1.27-2x5 WZ H4.9; JN1.27-2x5 WZ H4.9
JP701, JP710, JP713, JP714: 0R; R_Axial_DIN0204_L3.6mm_D1.6mm_P5.08mm_Horizontal
JP702, JP704, JP705, JP706, JP707, JP709, JP711, JP712, JP716: 0R; R_0603_1608Metric_Pad0.98x0.95mm_HandSolder
JP703: 8.12; Jumper_mm_L8.12_D1.2_H0.5
JP708, JP715: 0R; R_Axial_DIN0204_L3.6mm_D1.6mm_P7.62mm_Horizontal
OLED701: OLED_128x64_SSD1306; OLED_SSD1306_no_pins
R701, R725, R727, R728: 10k; R_0603_1608Metric_Pad0.98x0.95mm_HandSolder
R702, R703, R704, R706, R707, R708, R710, R711, R712, R726: 1k; R_0603_1608Metric_Pad0.98x0.95mm_HandSolder
R705, R709, R713: 220k; R_0603_1608Metric_Pad0.98x0.95mm_HandSolder
R714, R715, R716: 44k; R_0603_1608Metric_Pad0.98x0.95mm_HandSolder
R717, R718, R719: 22k; R_0603_1608Metric_Pad0.98x0.95mm_HandSolder
R720, R721, R722: 11k; R_0603_1608Metric_Pad0.98x0.95mm_HandSolder
R723, R724: 4k7; R_0603_1608Metric_Pad0.98x0.95mm_HandSolder
SW701, SW702, SW703: EncSw; RotaryEncoderSwitch_Oblong
TFT701: TFT_2.8in_320x240; TFT_2.8_IN_320x240
TP701, TP702, TP703, TP704, TP705, TP706, TP707, TP708, TP709: TestPoint; TestPoint_THTPad_D1.0mm_Drill0.5mm
U701: STM32G431K8Tx; LQFP-32_7x7mm_P0.8mm
Y701: 20 MHz; Crystal_SMD_3225-4Pin_3.2x2.5mm_HandSoldering

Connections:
/Block diagram/HMI/BOOT0: J706.2, R728.1, U701.31 (PB8)
/Block diagram/HMI/DISP_CS: J705.3, U701.9 (PA4)
/Block diagram/HMI/DISP_DC: JP714.1, U701.13 (PB0)
/Block diagram/HMI/DISP_MISO: JP707.1, JP712.1, U701.11 (PA6)
/Block diagram/HMI/DISP_MOSI: JP709.1, JP713.1, U701.12 (PA7)
/Block diagram/HMI/DISP_RST: JP716.1, U701.20 (PA10)
/Block diagram/HMI/DISP_SCK: J705.7, JP711.1, U701.10 (PA5)
/Block diagram/HMI/DISP_SCL: J703.3, R723.2, U701.19 (PA9)
/Block diagram/HMI/DISP_SDA: J703.4, R724.2, U701.18 (PA8)
/Block diagram/HMI/FREQ: C702.1, R705.2, R714.2, R717.2, R720.2, TP701.1, U701.7 (PA2)
/Block diagram/HMI/LV_NRST: J701.9, J708.1, R701.2
/Block diagram/HMI/LV_RX: J701.1, TP709.1, U701.30 (PB7)
/Block diagram/HMI/LV_SWDCLK: J701.10, J708.2
/Block diagram/HMI/LV_SWDIO: J701.8, J708.4
/Block diagram/HMI/LV_TX: J701.3, TP707.1, U701.29 (PB6)
/Block diagram/HMI/NRST: J707.1, R725.2, U701.4 (PG10)
/Block diagram/HMI/PER: C704.1, R713.2, R716.2, R719.2, R722.2, TP703.1, U701.6 (PA1)
/Block diagram/HMI/SL3: C705.1, C706.1, C710.1, C713.1, D701.2 (A), D702.2 (A), J701.6, J703.2, J705.1, J705.8, J706.1, J707.7, J707.8, J708.7, J708.8, JP702.2 (B), JP703.2 (B), R701.1, R723.1, R724.1, R725.1, U701.1 (VDD)
/Block diagram/HMI/SL3_A: C709.1, JP705.2 (B), U701.15 (VDDA)
/Block diagram/HMI/SL3_J: C707.1, C708.1, JP703.1 (A), JP705.1 (A), U701.17 (VDD)
/Block diagram/HMI/ST_LED: R726.2, R727.1, TP708.1, U701.5 (PA0)
/Block diagram/HMI/SUP: C703.1, R709.2, R715.2, R718.2, R721.2, TP702.1, U701.8 (PA3)
/Block diagram/HMI/SWDCLK: J707.2, U701.24 (PA14)
/Block diagram/HMI/SWDIO: J707.4, U701.23 (PA13)
/Block diagram/HMI/SWO: J707.3, U701.26 (PB3)
/Block diagram/HMI/TCH_CS: JP710.1, JP715.2 (B)
/Block diagram/HMI/TCH_IRQ: J705.14, JP708.1 (A)
/Block diagram/HMI/USB_DM: JP706.2, U701.21 (PA11)
/Block diagram/HMI/USB_DP: JP704.2, U701.22 (PA12)
Earth: J702.6 (Shield), JP701.2
GND: C701.2, C702.2, C703.2, C704.2, C705.2, C706.2, C707.2, C708.2, C709.2, C710.2, C711.2, C712.2, C713.2, J701.5, J702.5 (GND), J703.1, J705.2, J707.5, J707.6, J708.5, J708.6, R727.2, R728.2, SW701.C, SW701.S2, SW702.C, SW702.S2, SW703.C, SW703.S2, U701.14 (VSSA), U701.16 (VSS), U701.32 (VSS), Y701.2 (G), Y701.4 (G)
unnamed: D701.1 (K), D702.1 (K), R726.1
unnamed: J701.2, JP701.1
unnamed: J702.3 (D+), JP704.1
unnamed: J702.2 (D-), JP706.1
unnamed: J702.4 (ID), TP705.1
unnamed: J702.1 (VBUS), TP704.1
unnamed: J705.4, JP716.2
unnamed: J705.5, JP714.2
unnamed: J705.6, JP713.2
unnamed: J705.9, JP712.2
unnamed: J705.10, JP711.2
unnamed: J705.11, JP710.2
unnamed: J705.12, JP709.2
unnamed: J705.13, JP707.2
unnamed: C701.1, JP702.1 (A), R702.1, R703.1, R704.1, R705.1, R706.1, R707.1, R708.1, R709.1, R710.1, R711.1, R712.1, R713.1
unnamed: JP708.2 (B), U701.27 (PB4)
unnamed: JP715.1 (A), U701.25 (PA15)
unnamed: R702.2, R714.1, SW701.B
unnamed: R703.2, R717.1, SW701.A
unnamed: R704.2, R720.1, SW701.S1
unnamed: R706.2, R715.1, SW702.B
unnamed: R707.2, R718.1, SW702.A
unnamed: R708.2, R721.1, SW702.S1
unnamed: R710.2, R716.1, SW703.B
unnamed: R711.2, R719.1, SW703.A
unnamed: R712.2, R722.1, SW703.S1
unnamed: TP706.1, U701.28 (PB5)
unnamed: C711.1, U701.2 (PF0), Y701.1
unnamed: C712.1, U701.3 (PF1), Y701.3

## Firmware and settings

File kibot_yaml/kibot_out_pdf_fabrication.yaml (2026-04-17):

# KiBot output for generating Fabrication Document in PDF format
# https://kibot.readthedocs.io/en/latest/configuration/outputs/pcb_print.html

kibot:
  version: 1

outputs:
- name: @NAME@
  comment: '@COMMENT@'
  type: pcb_print
  category: '@DIR@'
  dir: '@DIR@'
  options:
    colored_pads: false
    colored_vias: false
    color_theme: '@COLOR_THEME@'
    output: '%f-fabrication%I%v.%x'
    format: 'PDF'
    title: '@DOC_TITLE@ Document'
    realistic_solder_mask: false
    dpi: 1200
    dnf_filter: _kibom_dnf_Config
    frame_plot_mechanism: 'internal' 
    sheet_reference_layout: '@SHEET_WKS@'
    drill:
      unify_pth_and_npth: '@PTH_NPTH@'
      group_slots_and_round_holes: @GROUP_ROUND_SLOTS@
    include_table:
      outputs:
        - name: '@NAME_TP_TOP@'
          text_alignment: 'left'
          invert_columns_order: false
          border_width: 0.4
          header_rule_width: 0.2
          horizontal_rule_width: 0
          vertical_rule_width: 0.2
          top_rule_width: 0.2
          bottom_rule_width: 0.2
          column_spacing: 2
          force_font_width: 1.27 # mm
        - name: '@NAME_TP_BOTTOM@'
          text_alignment: 'right'
          invert_columns_order: true
          border_width: 0.4
          header_rule_width: 0.2
          horizontal_rule_width: 0
          vertical_rule_width: 0.2
          top_rule_width: 0.2
          bottom_rule_width: 0.2
          column_spacing: 2
          force_font_width: 1.27 # mm
        - name: '@NAME_IMPEDANCE_TABLE@'
          text_alignment: 'left'
          invert_columns_order: false
          border_width: 0.4
          header_rule_width: 0.2
          horizontal_rule_width: 0
          vertical_rule_width: 0.2
          top_rule_width: 0.2
          bottom_rule_width: 0.2
          row_spacing: 3
          column_spacing: 2
          row_spacing: 3
        - name: '@NAME_DRILL_TABLE@'
          text_alignment: 'left'
          invert_columns_order: false
          border_width: 0.4
          header_rule_width: 0.2
          horizontal_rule_width: 0
          vertical_rule_width: 0.2
          top_rule_width: 0.2
          bottom_rule_width: 0.2
          row_spacing: 3
          column_spacing: 2
          force_font_width: 1 # mm

    pages:
      - scaling: @SCALING@
        title: '@DOC_TITLE@'
        sheet: 'Top Fabrication (Scale @SCALING@:1)'
        layer_var: 'Top Fabrication (Scale @SCALING@:1)'
        sheet_reference_color: '#000000'
        colored_holes: true
        holes_color: "#FFFFFF"
        layers:
          - layer: Edge.Cuts
            color: '#000000'
          - layer: F.Cu
            color: '#F2F2F2'
          - layer: F.Mask
            color: '#E2E2E2'
          - layer: F.Paste
            color: '#E2E2E2'
          - layer: F.Silkscreen
            color: '#DBDBDB'
          #- layer: F.Fab
          #  plot_footprint_refs: false
          #  plot_footprint_values: false
          #  color: '#818181'
          - layer: F.Dimensions
            color: '#000000'

      - scaling: @SCALING@
        mirror: true
        mirror_pcb_text: false
        title: '@DOC_TITLE@'
        sheet: 'Bottom Fabrication (Scale @SCALING@:1)'
        layer_var: 'Bottom Fabrication (Scale @SCALING@:1)'
        sheet_reference_color: '#000000'
        colored_holes: true
        holes_color: "#FFFFFF"
        layers:
          - layer: Edge.Cuts
            color: '#000000'
          - layer: B.Cu
            color: '#F2F2F2'
          - layer: B.Mask
            color: '#E2E2E2'
          - layer: B.Paste
            color: '#E2E2E2'
          - layer: B.Silkscreen
            color: '#DBDBDB'
          #- layer: B.Fab
          #  plot_footprint_refs: false
          #  plot_footprint_values: false
          #  color: '#818181'
          - layer: B.Dimensions
            color: '#000000'

      - scaling: @SCALING@
        title: '@DOC_TITLE@'
        sheet: 'Drill Drawing (%lp)'
        layer_var: 'Drill Drawing %lp (Scale @SCALING@:1)'
        sheet_reference_color: '#000000'
        colored_holes: true
        holes_color: "#FFFFFF"
        repeat_for_layer: '@LAYER_DRILL_MAP@'
        repeat_layers: 'drill_pairs'
        layers:
          - layer: '@LAYER_DRILL_MAP@'
            color: '#000000'
          - layer: 'Edge.Cuts'
            color: '#000000'
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

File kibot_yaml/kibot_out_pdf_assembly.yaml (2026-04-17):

# KiBot output for generating Assembly Document in PDF format
# https://kibot.readthedocs.io/en/latest/configuration/outputs/pcb_print.html

kibot:
  version: 1

outputs:
- name: @NAME@
  comment: '@COMMENT@'
  type: pcb_print
  category: '@DIR@'
  dir: '@DIR@'
  options:
    colored_vias: false
    colored_pads: false
    color_theme: '@COLOR_THEME@'
    output: '%f-assembly%I%v.%x'
    format: 'PDF'
    title: '@DOC_TITLE@ Document'
    realistic_solder_mask: false
    dpi: 1200
    dnf_filter: _kibom_dnf_Config
    # dnf_filter: '_null'
    sheet_reference_layout: '@SHEET_WKS@'
    include_table:
      outputs:
        - name: '@NAME_COMP_COUNT@'
          text_alignment: 'left'
          invert_columns_order: false
          border_width: 0.4
          header_rule_width: 0.2
          horizontal_rule_width: 0
          vertical_rule_width: 0
          top_rule_width: 0
          bottom_rule_width: 0
          row_spacing: 3
          column_spacing: 2
    pages:
      - scaling: @SCALING@
        layer_var: ''
        title: '@DOC_TITLE@'
        sheet: Top/Bottom View
        sheet_reference_color: '#000000'
        layers:
          - layer: '@LAYER_TITLE_PAGE@'
            color: '#000000'

      - scaling: @SCALING@
        layer_var: "Top Assembly (Scale @SCALING@:1)"
        title: '@DOC_TITLE@'
        sheet: Top Assembly (Scale @SCALING@:1)
        sheet_reference_color: '#000000'
        colored_holes: true
        holes_color: "#FFFFFF"
        layers:
          - layer: Edge.Cuts
            color: '#000000'
          - layer: F.Cu
            color: '#EEDAB5'
          - layer: F.Mask
            color: '#B9B9B9'
          - layer: F.Paste
            color: '#E1A98E'
          #- layer: F.Silkscreen
          #  color: '#DB9DE1'
          - layer: F.Fab
            exclude_filter: '@FAB_EXCLUDE_FILTER@'
            color: '#744679'
          - layer: '@LAYER_ASSEMBLY_TEXT_TOP@'
            color: '#000000'
          - layer: '@LAYER_DNP_CROSS_TOP@'
            color: '#D63034'

      - scaling: @SCALING@
        layer_var: "Bottom Assembly (Scale @SCALING@:1)"
        mirror: true
        mirror_pcb_text: false
        title: '@DOC_TITLE@'
        sheet: Bottom Assembly (Scale @SCALING@:1)
        sheet_reference_color: '#000000'
        colored_holes: true
        holes_color: "#FFFFFF"
        layers:
          - layer: Edge.Cuts
            color: '#000000'
          - layer: B.Cu
            color: '#D5DBF4'
          - layer: B.Mask
            color: '#B9B9B9'
          - layer: B.Paste
            color: '#BCB9DD'
          #- layer: B.Silkscreen
          #  color: '#DB9DE1'
          - layer: B.Fab
            exclude_filter: '@FAB_EXCLUDE_FILTER@'
            color: '#400080'
          - layer: '@LAYER_ASSEMBLY_TEXT_BOTTOM@'
            color: '#000000'
          - layer: '@LAYER_DNP_CROSS_BOTTOM@'
            color: '#D63034'

...
definitions:
  NAME: pdf_assembly
  COMMENT: Assembly document in PDF format
  DIR: Manufacturing/Assembly
  DOC_TITLE: Assembly
  COLOR_THEME: Altium_Theme
  SHEET_WKS: ${KIPRJMOD}/Templates/KDT_Template_PCB_GIT_A3.kicad_wks
  SCALING: 1.0
  FAB_EXCLUDE_FILTER: exclude_testpoints
  LAYER_TITLE_PAGE: TitlePage
  LAYER_ASSEMBLY_TEXT_TOP: F.AssemblyText
  LAYER_ASSEMBLY_TEXT_BOTTOM: B.AssemblyText
  LAYER_DNP_CROSS_TOP: F.DNP
  LAYER_DNP_CROSS_BOTTOM: B.DNP
  NAME_COMP_COUNT: csv_comp_count

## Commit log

2026-04-14 started migration
    [Project Architecture.kicad_sch, Section A - Title A.kicad_sch, Strobe_HMI.kicad_pcb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]
2026-04-14 Update Outputs
    [Strobe_HMI-bom.csv]
2026-04-14 Refactoring sch
    [Block Diagram.kicad_sch, Block diagram.kicad_sch, HMI.kicad_sch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]
2026-04-15 sch refactoring complete
    [Block diagram.kicad_sch, HMI.kicad_sch, Strobe_HMI.kicad_pcb]
2026-04-15 Migrated PCB file to template, switched to preliminary
    [HMI.kicad_sch, Strobe_HMI.kicad_pcb]
2026-04-16 updated pcb template
    [Block diagram.kicad_sch, HMI.kicad_sch, Revision History.kicad_sch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]
2026-04-16 added some libraries, TFT still missing
    [Strobe_HMI.kicad_pcb]
2026-04-17 TFT 3D added
    [HMI.kicad_sch, Strobe_HMI.kicad_pcb]
2026-04-17 Adding silk and edges to fab doc
    [Strobe_HMI.kicad_pcb]
2026-04-17 changing sheet sizes
    [Strobe_HMI.kicad_sch]
2026-04-17 still trying to change sheet size
    [Strobe_HMI.kicad_sch]
2026-04-18 Added code, pictures, readme, updated sch size and notes, changed to checked
    [Block diagram.kicad_sch, HMI.kicad_sch, Revision History.kicad_sch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]
2026-04-18 Preparing release
    [HMI.kicad_sch, Strobe_HMI.kicad_pcb]
2026-04-19 Update Outputs (release)
    [Strobe_HMI.kicad_pcb]
2026-04-26 Moved source code
    [Revision History.kicad_sch, Strobe_HMI.kicad_sch]
